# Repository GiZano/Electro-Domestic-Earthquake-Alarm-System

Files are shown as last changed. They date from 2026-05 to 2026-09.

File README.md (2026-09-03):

<div align="center">

# 🌋 QuakeGuard
### Distributed Earthquake Early Warning System

**Full-Stack IoT Architecture for Real-Time Earthquake Detection**




























> 📚 **Technical Specification:** A comprehensive architecture whitepaper is available in the `docs/` directory, compiled via Typst. For a browsable, topic-by-topic reference, check out the [project Wiki](https://github.com/GiZano/QuakeGuard/wiki).

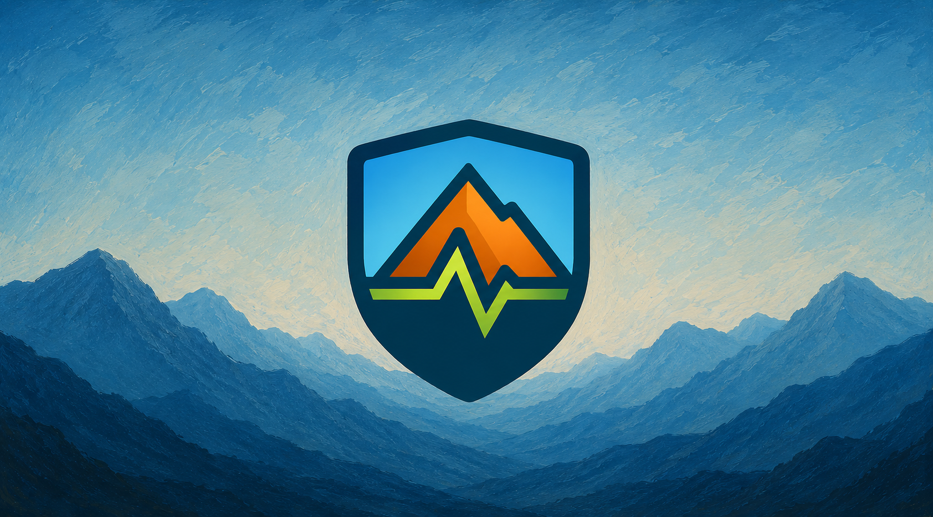
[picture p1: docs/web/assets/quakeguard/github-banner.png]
QuakeGuard Logo


</div>

---

## 📖 Overview

**QuakeGuard** is a full-stack IoT architecture for real-time detection, analysis, and reporting of seismic events. The system transforms everyday household appliances — washing machines, TVs, refrigerators — into a distributed seismic sensor network, each node capable of detecting and reporting earthquake activity autonomously.

Intelligent edge sensors (ESP32-C3 + ADXL345) analyze vibrations locally using professional-grade algorithms and transmit cryptographically signed data to an asynchronous cloud backend. The backend is engineesred to handle the massive traffic spikes — the **Thundering Herd** effect — typical during widespread seismic events, ensuring reliable alarm delivery without bottlenecking. A React Native mobile app receives real-time haptic and visual alerts via WebSocket.

### QuakeGuard Proprietary Hardware

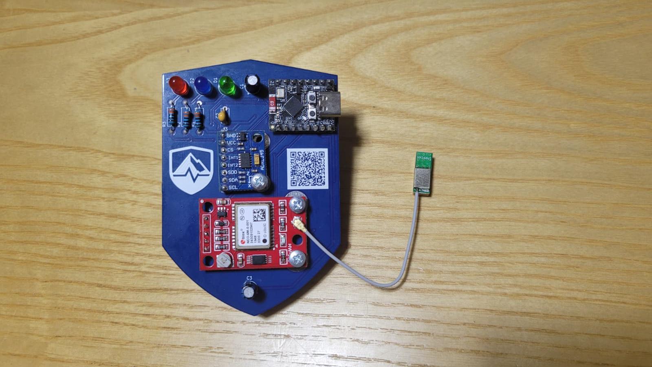
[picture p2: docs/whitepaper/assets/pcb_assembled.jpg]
QuakeGuard v2.0 Assembled PCB


*The QuakeGuard v2.0 fully assembled PCB, featuring the ESP32-C3 SuperMini, the ADXL345 accelerometer, and the u-blox GNSS module. For a complete list of required components, refer to the [Bill of Materials (BOM)](https://github.com/GiZano/QuakeGuard/wiki/Bill-of-Materials) in the Wiki.*

---

## 🏗️ System Architecture

```
ESP32-C3 + ADXL345
       │
       │  MQTT (signed payload)
       ▼
MQTT Bridge ──► POST /readings/ ──► ECDSA Verification
                                              │
                                              ▼
                                        Redis Queue
                                              │
                                              ▼
                                     Background Worker ────►┌───────────┐
                                      │           │ (Queue)  │ AI Worker │
                                      ▼           ▼          │ (Ollama)  │
                               PostgreSQL    Redis Pub/Sub ◄─└─────┬─────┘
                               + PostGIS               │
                                                   ▼
                                            WebSocket Broadcast
                                                  │
                                                  ▼
                                        React Native Mobile App
                                        (Haptic + Visual Alert)
```

The project follows **Microservices** and **Event-Driven Design** principles across three fully independent layers.

---

## 📡 IoT Edge (`firmware/`)

| Feature | Detail |
|---|---|
| Hardware | ESP32-C3 SuperMini + ADXL345 Accelerometer |
| Sampling Rate | 100 Hz |
| Detection Algorithm | STA/LTA (Short Term / Long Term Average) |
| Signal Processing | Digital High-Pass Filter (HPF) to remove gravity |
| Data Structure | Statically allocated Ring Buffers (`RingBuffer<100>` STA, `RingBuffer<1000>` LTA) |
| Security | ECDSA NIST256p cryptographic signing on every payload |
| Transmission | MQTT publish to `quakeguard/telemetry` |
| Provisioning | Automated device handshake on first boot via `POST /devices/register` |
| Secret Injection | Compile-time `ENROLLMENT_TOKEN` via PlatformIO pre-script + `#error` fail-fast |

---

## ☁️ Backend (`backend/`)

| Feature | Detail |
|---|---|
| Framework | FastAPI (Python 3.11), fully async |
| Security | API Key auth, ECDSA signature verification, Anti-Replay (300s window) |
| Message Broker | Redis — decouples ingestion from processing |
| Rate Limiting | Fixed-window 50 req/s per IP via Redis |
| Alert Engine | ML-like magnitude proxy (`M = log10(PGA_calib) + b`), threshold M ≥ 4.5 |
| Deduplication | Redis TTL cooldown lock per zone (60s), prevents alert storms |
| Persistence | PostgreSQL + PostGIS with `recorded_at` timestamps |
| Zone Assignment | Automatic via PostGIS `ST_Contains` spatial query, ordered by `ST_Area` ascending |
| Zone Seeding | 8 pre-populated global macro-regions + "Unknown Region" fallback |
| Observability | `GET /health` — concurrent PostgreSQL + Redis ping |
| Secrets | Fail-fast `RuntimeError` on missing env vars at startup |
| MQTT Bridge | `mqtt_subscriber.py` — forwards MQTT payloads to the secure HTTP pipeline |
| Edge AI | Asynchronous emergency report generation via local Ollama (Llama 3.2) |

---

## 📱 Frontend (`mobile/`)

| Feature | Detail |
|---|---|
| Framework | React Native (Expo) with TypeScript |
| Navigation | Expo Router — 3-tab Bottom Navigator (Monitor, Sensors Map, Settings) |
| State Management | Zustand slices (`usePreferencesStore`, `useAlertStore`) |
| Server State | TanStack Query + Axios — caching, background refetch, retry |
| Real-Time | WebSocket context with exponential backoff reconnection |
| Alert Delivery | SOS haptic vibration pattern + OS push notification via `expo-notifications` |
| Alert History | In-session feed of last 10 critical events |
| AI Report Banner | Inline AI-generated emergency report (summary + recommendations) for the latest alert, with "Report unavailable" badge on failures |
| Offline Mode | Toggle silences WebSocket, halts all TanStack Query polling |
| Notifications | `notificationsEnabled` toggle gates haptics and push notifications |
| Safe Areas | `react-native-safe-area-context` — Dynamic Island and punch-hole compatible |

---

## 🔐 Security Model

Data integrity is paramount in an emergency system. Every telemetry packet is cryptographically secured end-to-end.

```
ESP32 signs payload with ECDSA NIST256p (SHA256)
         ↓
Backend verifies signature against registered public key
         ↓
Timestamp validated within 300-second window (Anti-Replay)
         ↓
API Key checked on every request (X-API-Key header)
         ↓
Payload accepted → Redis Queue
```

**Threat model coverage:**
- ✅ Man-in-the-Middle (MitM) — ECDSA signature verification
- ✅ Spoofing — public key registration + signature check
- ✅ Replay attacks — 300-second timestamp window
- ✅ Brute force — rate limiting 50 req/s per IP
- ✅ Unauthorized access — API Key + enrollment token fail-fast

---

## 🚀 Quick Start

### Prerequisites

- Docker Desktop & Docker Compose
- PlatformIO (VS Code Extension)
- Node.js 18+ & Expo Go (mobile)
- A mobile hotspot or shared WiFi network for ESP32 + backend connectivity

### 1. Configure Environment Variables

```bash
cd backend
cp .env.example .env
```

Edit `.env` and set the required secrets:

```env
# --- Application Secrets ---
IOT_API_KEY=your_secret_key
MOBILE_WS_TOKEN=your_ws_token
ENROLLMENT_TOKEN=your_enrollment_token

# --- Database ---
POSTGRES_DB=quakeguard_db
POSTGRES_USER=developer
POSTGRES_PASSWORD=your_db_password
API_PORT=8000

# --- Cloud MQTT (HiveMQ) ---
MQTT_BROKER=your-cluster-id.s1.eu.hivemq.cloud
MQTT_PORT=8883
MQTT_USERNAME=your_mqtt_username
MQTT_PASSWORD=your_mqtt_password

# --- AI Emergency Reports (hybrid Edge AI architecture) ---
AI_REPORT_ENABLED=true
OLLAMA_HOST=http://127.0.0.1:11434
OLLAMA_MODEL=llama3.2:1b
```

> ⚠️ The backend will refuse to start if any of these are missing — this is intentional fail-fast behavior.

> 💡 **Edge AI Architecture (v2.0.0):** To maximize hardware efficiency and avoid Docker's GPU passthrough overhead, QuakeGuard employs an industrial **Hybrid Edge AI** pattern (similar to NVIDIA Jetson or Tesla FSD architectures). The core AI inference engine (Ollama) runs bare-metal on the host Linux OS, while the application microservices run in Docker and communicate via `network_mode: "host"`.
> 
> **To enable on-premise AI reports:**
> 1. Install Ollama natively on your Linux host: `curl -fsSL https://ollama.com/install.sh | sh`
> 2. Pull the model natively: `ollama pull llama3.2:1b`
> 3. Start the Docker stack with the AI worker profile: `docker compose --profile ai up --build -d`
> 
> Reports are generated entirely on your machine: telemetry never leaves the host.

### 2. Launch the Backend Stack

```bash
cd backend
docker compose up --build -d
```

| Endpoint | URL |
|---|-----|
| API | `http://localhost:8000` |
| Swagger UI | `http://localhost:8000/docs` |
| Health Check | `http://localhost:8000/health` |

### 3. Configure and Flash the IoT Firmware

```bash
cd firmware
cp esp32_config.env.example esp32_config.env
# Edit esp32_config.env with your network IP and ENROLLMENT_TOKEN
```

Flash via PlatformIO. On first boot the device will:
1. Open a WiFi captive portal (`QuakeGuard-Setup`)
2. Connect to your network
3. Automatically register with the backend and receive a `sensor_id`

> 💡 If the sensor registers with `latitude=0.0, longitude=0.0` it will be assigned to "Unknown Region". Hardcode your coordinates in `main.cpp` for correct zone assignment until GPS integration is complete.

### 4. Launch the Mobile App

```bash
cd mobile
npm install
```

Update `constants/config.ts` with your machine's local IP:

```typescript
export const API_BASE_URL = "http://YOUR_LOCAL_IP:8000";
```

Create `.env` in the mobile root:

```env
EXPO_PUBLIC_IOT_API_KEY=your_secret_key
EXPO_PUBLIC_MOBILE_WS_TOKEN=your_ws_token
```

```bash
npx expo start
```

Scan the QR code with Expo Go. Ensure your phone is on the **same WiFi network** as the backend machine.

---

## 🧪 Stress Test

Validates the full pipeline: ingestion → Redis → worker → PostGIS → WebSocket alerts.

```bash
cd backend
export API_URL="http://localhost:8000"
export NUM_SENSORS=150
export CONCURRENCY_LIMIT=50
python -m tests.stress_test
```

**Three phases:**

| Phase | What it tests |
|---|---|
| 🔥 Phase 1 — Firehose | 150 concurrent sensors, rate limiter validation |
| ⚔️ Phase 2 — Security | Bad signature blocked (401), Replay attack blocked (403) |
| 🔍 Phase 3 — E2E | DB persistence verified via polling `GET /sensors/{id}/statistics` |

A successful run ends with `🏆 SYSTEM CERTIFIED`.

---

## 🎮 Demo Mode

Trigger a simulated earthquake instantly from Swagger UI without running the stress test:

```
POST /demo/trigger-earthquake
```

Default payload (works with empty `{}`):
```json
{
  "zone_id": 1,
  "magnitude": 7.5,
  "message": "Simulated Critical Event"
}
```

This publishes directly to the Redis `quake_alerts` channel, bypassing the IoT pipeline entirely and triggering the mobile app alert UI within milliseconds.

---

## 🗺️ Geographic Zones

The database is pre-seeded with 8 global macro-regions. Sensors are automatically assigned to the correct zone via PostGIS spatial query at registration time.

| Zone | Coverage |
|---|---|
| Italy - North | Lombardy, Veneto, Piedmont |
| Italy - Center | Tuscany, Lazio, Umbria |
| Italy - South & Islands | Campania, Sicily, Sardinia |
| Western Europe | France, Spain, Germany, UK |
| North America | USA, Canada, Mexico |
| South America | Brazil, Argentina, Chile |
| East Asia | China, Japan, India |
| Unknown Region | Fallback for unmapped coordinates |

---

## 🔄 CI/CD Pipeline

| Workflow | Trigger | Checks |
|---|---|---|
| `backend-ci.yml` | `backend/**` | Bandit, Safety, stress test |
| `frontend-ci.yml` | `mobile/**` | ESLint, npm audit |
| `iot-ci.yml` | `firmware/**` | PlatformIO compilation |
| `pr-lint.yml` | All PRs | Semantic PR title (`type(scope): message`) |
| `devops-ci.yml` | `.github/workflows/**` | Actionlint workflow validation |

---

## 🗂️ Project Structure

```
QuakeGuard/
├── backend/
│   ├── src/
│   │   ├── main.py              # FastAPI gateway + REST endpoints
│   │   ├── security.py          # ECDSA, API Key, Anti-Replay
│   │   ├── worker.py            # Redis consumer + magnitude + alert engine + AI enqueue
│   │   ├── ai_report_worker.py  # Dedicated AI report consumer (Ollama + state machine)
│   │   ├── ollama_client.py     # Deterministic LLM client (anti-hallucination)
│   │   ├── mqtt_subscriber.py   # MQTT to HTTP bridge
│   │   ├── seed.py              # Geographic zone seeder
│   │   ├── models.py            # SQLAlchemy ORM models (+ EmergencyReport)
│   │   ├── schemas.py           # Pydantic request/response schemas
│   │   └── database.py          # DB engine and session factory
│   ├── tests/
│   │   ├── stress_test.py       # Critical E2E stress test suite
│   │   └── unit/                # Unit tests (worker, ollama client, AI worker, models, ...)
│   ├── init-scripts/
│   │   └── ollama-entrypoint.sh # Auto-pulls the Ollama model on startup
│   ├── build.ps1                # Automatic container publish
│   ├── docker-compose.yml
│   ├── Dockerfile
│   ├── mosquitto.conf
│   ├── requirements.txt         # Python requirements for backend development
│   └── .env.example
├── mobile/
│   ├── app/                         # Expo Router screens
│   │   └── (tabs)/
│   │       ├── index.tsx            # Monitor / Dashboard
│   │       ├── map.tsx              # Sensor Network Map
│   │       └── settings.tsx         # User Preferences
│   ├── api/                         # Axios client + TanStack Query hooks
│   ├── components/                  # Shared UI components
│   ├── store/                       # Zustand state slices
│   ├── context/
│   │   └── WebSocketContext.tsx     # Real-time alert context
│   └── constants/
│       └── config.ts                # Centralized configuration
├── firmware/
│   ├── src/
│   │   ├── main.cpp             # FreeRTOS tasks, STA/LTA, MQTT, provisioning
│   │   ├── DetectionCore.h      # Pure-C++ STA/LTA core (shared firmware/host, R1)
│   │   └── RingBuffer.h         # Statically allocated circular buffer
│   ├── tools/
│   │   └── detect_cli.cpp       # Native host CLI (SIL replay, same core)
│   ├── test/                    # Test scripts to insert into the ESP32
│   ├── key-generator/           # ECDSA key generator for backend testing
│   ├── esp32_config.env.example
│   ├── extra_script.py          # ENV variables injector
│   └── platformio.ini
├── research/                    # SIL validation (ROADMAP R1)
│   ├── fetch_itaca.py           # ITACA download (graceful degradation) / synthetic fallback
│   ├── synthetic.py             # Realistic synthetic dataset generator
│   ├── calibrate_io.py          # Dataset layout I/O + path-injection guard
│   ├── orchestrator.py          # Compile & run the host C++ CLI (subprocess bridge)
│   ├── metrics.py               # Sensitivity, False-Alarm Rate, latency, ROC
│   ├── calibrate.py             # TRIGGER_RATIO x NOISE_FLOOR sweep (F1 maximization)
│   ├── plot_roc.py              # ROC curve figure for the paper
│   ├── requirements.txt         # matplotlib (optional, plotting)
│   └── README.md                # Dataset layout, unit conversion, licensing policy
└── docs/                            # Technical Documentation
    ├── main.typ                     # Typst Whitepaper Entrypoint
    ├── 01-architecture.typ          # System Architecture & Overview
    ├── 02-hardware.typ              # Hardware & Edge Computing (ESP32-C3)
    ├── 03-security.typ              # Cryptographic Security & Provisioning
    ├── 04-broker.typ                # Data Plane & Message Broker (MQTT)
    ├── 05-backend.typ               # Backend Services & Event Processing
    ├── 06-mobile.typ                # Mobile Client & Live Telemetry
    ├── 07-deployment.typ            # Deployment & CI/CD
    └── 08-ai.typ                    # AI Emergency Report Service (v1.2.0)
```

---

## 🔮 Roadmap

| Version | Focus |
|---|---|
| **v1.0** | ✅ Released — edge seismic detection on ESP32, local alerts |
| **v1.1** | ✅ Released — HiveMQ Cloud MQTT (TLS), ngrok HTTPS tunnel, security hardening |
| **v1.2** | ✅ Released — On-Premise AI Worker (Local Ollama / Llama 3.2) for privacy-preserving emergency reports |
| **v1.2.1** | ✅ Released — Geo-Zoning & Cooldown Fragmentation — geohash Redis zone index (FastAPI/PostGIS source of truth), per-area cooldown, GNSS-ready data model (`Sensor.last_fix_at`, `Reading.lat/lon`), per-zone live seismograph |
| **v1.2.2** | ✅ Released — Zero-Trust Serial Fallback — signed telemetry over USB CDC (serial) when MQTT is unreachable |
| **v2.0.0** | ✅ Released — Triangulation (multi-node spatial correlation), Hybrid Network Architecture, Automated DevOps Orchestration (Ptyxis), Local Factory Provisioning, GNSS sync, NTP+PPS, ADXL calibration, and INGV FDSN SIL validation |
| **v2.0.1** | ✅ Released — Documentation & Zenodo Sync: PDF/Wiki architectural coherence (Cloudflare, 300s anti-replay), CERN-OHL hardware licensing, SIL vs Firmware threshold clarification, and `CITATION.cff` bump |
| **v2.1** | Data Dashboards — Grafana dashboards for real-time visualization of seismic telemetry |
| **v2.1.1** | Timeseries DB & Mobile Fix — migration to TimescaleDB/InfluxDB; per-sensor chart isolation in React Native mobile |
| **v2.2** | Heterogeneous Edge Intelligence — hybrid Tier A (STA/LTA) + Tier B (quantized CNN) decision fusion |
| **Future** | Cloud IaC — Kubernetes + Terraform auto-scaling platform (see [ROADMAP.md](ROADMAP.md)) |

### #Research — Scientific Validation (SIL)

| Node | Focus |
|---|---|
| **#Research** | Parallel ongoing node — SIL cross-validation: replay of the exact production C++ STA/LTA core (`DetectionCore.h`) on the host via the same C++ source, Python-only as orchestrator, ROC metrics + AI benchmarking (latency P50/P99, hallucination rate). R1 pipeline (core isolation, host CLI, orchestrator, metrics, calibration) implemented; see [ROADMAP.md](ROADMAP.md) |

---

## 🏆 Awards & Recognition

QuakeGuard's architecture and real-world applicability have been recognized in the following academic and industrial contexts:

* 🥇 **1st Place Overall - Institute Project Day (2025):** Awarded best technical project out of ~20 prototypes across four engineering disciplines (Computer Science, Automation, Mechanics, Chemistry). The full-stack architecture was evaluated and awarded by an industrial jury featuring technical representatives from **Siemens, ABB, SORINT.lab, SAME, Ferrero, and Confindustria**.
* 🎓 **Academic Origin & Consultation:** The system's conceptualization originated during the 2025 CQIIA-MatNet Summer School (Università di Bergamo). The distributed network logic and spatial deployment strategy were subsequently refined following technical consultations with Prof. F. Finazzi.
* 🏅 **GF Marilli Competition:** [Currently competing - Pending evaluation].

---

## 📄 License

This project is licensed under the **GNU Affero General Public License v3.0 (AGPL-3.0)**.
See the [LICENSE](LICENSE) file for details.

---

<div align="center">

**Developed by [GiZano](https://giovanni-zanotti.is-a.dev) and [riccardo0731](https://riccardo0731.github.io)**
<br>
*Open Source — AGPL-3.0 License*
<br><br>

</div>

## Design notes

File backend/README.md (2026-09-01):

# QuakeGuard Backend Service

QuakeGuard is a distributed, high-throughput backend system designed for the real-time ingestion, cryptographic validation, and processing of seismic data from IoT devices.

This repository hosts the **API Gateway**, **Background Worker**, and **Persistence Layer** definitions, serving as the core infrastructure for an Earthquake Early Warning (EEW) system.

---

## 📂 Project Structure

The project is organized as a modular microservice architecture:

```text
backend/
└── api/
    ├── init-scripts/       # SQL initialization scripts (PostGIS)
    │   └── ollama-entrypoint.sh  # Auto-pulls the Ollama model on startup
    ├── src/                # Source Code
    │   ├── main.py         # FastAPI Gateway & REST Endpoints
    │   ├── worker.py       # Stream consumer (Redis Streams, batched persistence)
    │   ├── ingest.py       # Redis Streams ingestion substrate (group/DLQ/recovery)
    │   ├── timescale.py    # Idempotent TimescaleDB hypertable + aggregates migration
    │   ├── geo.py          # Geohash zone-index (Redis) + candidate pruning
    │   ├── ai_report_worker.py  # Dedicated AI report consumer (Ollama + state machine)
    │   ├── ollama_client.py     # Deterministic LLM client (anti-hallucination)
    │   ├── database.py     # SQLAlchemy Connection & Pool config
    │   ├── models.py       # ORM Models (GeoAlchemy2 + EmergencyReport)
    │   └── schemas.py      # Pydantic DTOs
    ├── scripts/
    │   └── load_test.py    # Load generator (N sensors at H Hz, stream or HTTP)
    ├── docker/
    │   └── postgres-timescale.Dockerfile  # TimescaleDB + PostGIS DB image
    ├── tests/              # Testing Suite
    │   ├── __init__.py
    │   ├── stress_test.py  # Load testing & ECDSA simulation tool
    │   └── unit/           # Unit tests (worker, ollama, AI worker, models)
    ├── .venv/              # Local Python Environment
    ├── build.ps1           # Build helper script
    ├── docker-compose.yml  # Container orchestration
    ├── Dockerfile          # Python runtime environment
    └── requirements.txt    # Project dependencies
```

---

## 🏗 System Architecture

The system operates on three decoupled layers:

1.  **Ingestion Layer (FastAPI):**
    * **Role:** Acts as the secure gateway for IoT sensors.
    * **Features:**
        * Asynchronous request handling (`async/await`).
        * **Zero-Trust Security:** Enforces ECDSA (NIST256p) signature verification with SHA-256 hashing on every payload.
        * **Polyglot Crypto Support:** Handles both DER (MbedTLS/C++) and RAW (Python/JS) signature formats.
        * **O(1) enqueue:** Valid payloads are appended to a **Redis Streams** bus (`readings:stream`) instead of touching the database — the API stays fast no matter how many sensors emit.

2.  **Processing Layer (Worker):**
    * **Role:** Drains the stream via consumer groups and persists + analyzes the data.
    * **Features:**
        * **Horizontally scalable:** `docker compose scale worker=N` — Redis balances deliveries across consumers; `XAUTOCLAIM` reclaims entries left pending by crashed workers (at-least-once delivery).
        * **Batched persistence:** a stream batch (default 64 heartbeats) is committed to PostgreSQL in one transaction.
        * **Poison-message isolation:** unparseable/failing heartbeats are parked on the `readings:dlq` stream and ACKed, so they can never stall the group.
        * Triggers persistent `Alerts` when predefined thresholds are breached (Redis `SET NX` cooldown deduplication).

3.  **Persistence Layer:**
    * **TimescaleDB + PostGIS (single image):** `readings` is a TimescaleDB *hypertable* chunked on `recorded_at` (continuous aggregate `readings_minute` serves the dashboard rollups; compression + retention). PostGIS remains the authoritative source for zone geometry.
    * **Redis:** Streams for ingestion buffering, Pub/Sub for real-time alert distribution, geohash zone-index + cooldown keys for the alerting fast path.

---

## 🚀 Installation & Setup

### Prerequisites
* **Docker** & **Docker Compose**
* **Python 3.11+** (Optional, for local testing)

### 1. Environment Configuration
The system relies on environment variables. Ensure your `.env` or Docker configuration includes:

```env
DATABASE_URL=postgresql://developer:development_pass@db:5432/monitoraggio_db
REDIS_URL=redis://redis:6379/0

# --- Optional: AI Emergency Reports ---
# Enables report enqueueing from the alert engine (default: false)
AI_REPORT_ENABLED=true
OLLAMA_HOST=http://ollama:11434
OLLAMA_MODEL=llama3.2:1b
```

### 2. Build and Deployment
Navigate to the `api` directory and launch the stack:

```bash
cd api
docker-compose up -d --build
```

The API will be accessible at: `http://localhost:8000`

### 3. Optional — Enable AI Emergency Reports (Hybrid Edge AI)
To maximize performance and avoid Docker virtualization overhead for GPU drivers, QuakeGuard uses a hybrid Edge AI architecture (following NVIDIA Jetson/Tesla FSD best practices). The AI model runs natively on the host OS, while the `ai-worker` runs in Docker.

1. Install Ollama natively on your Linux host machine:
   `curl -fsSL https://ollama.com/install.sh | sh`
2. Download the model:
   `ollama pull llama3.2:1b`
3. Start the Docker stack with the `ai` profile:
   ```bash
   cd api
   docker-compose --profile ai up -d --build
   ```

The `ai-worker` container will automatically connect to your native Ollama instance using the host network. Reports are generated entirely on the host — telemetry never leaves your machine.

### 4. API Documentation
Interactive Swagger UI is available at:
`http://localhost:8000/docs`

---

## 📡 API Endpoints Overview

### 🛠️ Registration (Admin & Setup)
Endpoints for provisioning the infrastructure.

* **POST** `/zones/` - Create a new monitoring zone.
* **POST** `/sensors/` - Register a new sensor.
    * *Note:* Requires the sensor's ECDSA Public Key (Hex format).
* **GET** `/zones/` - Retrieve available zones.
* **GET** `/sensors/` - Retrieve registered sensors.

### 📍 Geo-Location (v1.2.1)
* **GET** `/zones/locate?latitude=..&longitude=..` - Resolve a GPS fix into the smallest containing monitored zone (powers "Detect my zone").
* **GET** `/zones/{zone_id}/readings` - Fetch the most recent readings emitted by sensors of a single zone (per-zone seismograph feed).
* **DELETE** `/zones/{zone_id}/readings` - Clear the telemetry emitted by a single zone (returns `{ "deleted": n }`).

### 📥 Data Ingestion (IoT)
* **POST** `/readings/` - High-frequency ingestion endpoint.
    * **Payload:** Telemetry data including `value`, `device_timestamp`, and `signature_hex`.
    * **Security:** Rejects any payload with an invalid or missing digital signature.

### 📊 Data Retrieval & Analytics
* **GET** `/zones/{zone_id}/alerts` - Retrieve confirmed seismic alerts for a specific area.
* **GET** `/sensors/{sensor_id}/statistics` - Get aggregated metrics (Count, Avg, Max, Min) for sensor diagnostics.

### 🤖 AI Emergency Reports (v1.2.0)
* **GET** `/reports/{alert_id}` - Retrieve the AI-generated emergency report for a confirmed alert (persisted; useful after a WebSocket reconnect).

### 🟢 System
* **GET** `/health` - Detailed status check of API, Database, and Redis connectivity.

---

## ⚙️ Technical Specifications

### Cryptography & Security
The backend enforces strict cryptographic standards to prevent spoofing or replay attacks:
* **Algorithm:** ECDSA (Elliptic Curve Digital Signature Algorithm).
* **Curve:** NIST P-256 (secp256r1).
* **Hash Function:** SHA-256.
* **Format:** Accepts **DER encoded** signatures (standard for ESP32/MbedTLS) with a fallback to RAW formats.

### High-Concurrency Configuration
To handle bursts of traffic during seismic events, the database engine is optimized:
* **Pool Size:** 40 persistent connections.
* **Max Overflow:** 60 additional temporary connections (Total capacity: 100 concurrent threads).
* **Pre-Ping:** Enabled to prevent stale connection errors.

### Scaling (right-sized)
| Tier | Configuration | Sustained write rate |
| :--- | :--- | :--- |
| 150 sensors (test) | 1 worker, default settings | ~30 msg/s (1 reading / 5 s) |
| 10k sensors | `scale worker=N`, TimescaleDB hypertable | ~2k msg/s (1 Hz each) on 1 Postgres node |
| 1M sensors | + EMQX federation, Kafka/Redpanda buffer, ClickHouse analytics | beyond single-node; ports are designed, not deployed |

The TimescaleDB migration (`src/timescale.py`) is idempotent and **fails closed**: on a stock PostGIS container every step is skipped with a warning and the service keeps running on the plain relational table. Provisioning happens automatically at startup and via `python -m src.timescale`.

Load generator for capacity planning:

```bash
# 150 sensors @ 1 Hz into the stream bus (matches the CI requirement)
python scripts/load_test.py --sensors 150 --hz 1 --duration 60
# End-to-end through the FastAPI ingress
python scripts/load_test.py --sensors 150 --hz 1 --mode http --api http://localhost:8000
```

---

## 🧪 Stress Testing

A specialized end-to-end stress suite lives in `tests/stress_test.py`. It simulates a fleet of **150 sensors** (configurable via `NUM_SENSORS`) firehosing cryptographically valid MQTT telemetry, verifies end-to-end persistence, and runs active security attacks (invalid signature + replay) against the API.

**To run the test:**

1.  Ensure the Docker stack is running.
2.  Install test dependencies:
    ```bash
    pip install aiohttp ecdsa aiomqtt
    ```
3.  Execute the script:
    ```bash
    python -m tests.stress_test
    ```

**Success Criteria:**
The test should report a 100% success rate (HTTP 202 Accepted) with no signature validation errors.

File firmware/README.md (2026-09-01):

# QuakeGuard - Distributed Earthquake Early Warning System
### Firmware Version: v2.0.0

## 1. Project Overview
QuakeGuard is an IoT-based seismic detection node designed for the **ESP32-C3 SuperMini** platform. It utilizes an **ADXL345** accelerometer to detect ground vibrations in real-time using the **STA/LTA (Short Term Average / Long Term Average)** algorithm.

Upon detecting a seismic event, the device constructs a JSON payload containing the magnitude and timestamp, cryptographically signs it using **ECDSA (NIST256p)**, and transmits it via HTTP POST to a central server.

## 2. Hardware Architecture

### Target Platform
* **Microcontroller:** ESP32-C3 SuperMini (RISC-V)
* **Sensor:** ADXL345 Digital Accelerometer (I2C Interface)

### Pin Configuration (Critical)
Due to the specific layout of the ESP32-C3 SuperMini, the I2C bus is forced via software to the following GPIOs:

| Component Pin | ESP32-C3 GPIO | Notes |
| :--- | :--- | :--- |
| **SDA** | **GPIO 7** | Requires internal Pull-Up (Handled by Firmware) |
| **SCL** | **GPIO 8** | Requires internal Pull-Up (Handled by Firmware) |
| **VCC** | **3.3V** | **Do not use 5V** (Risk of sensor damage) |
| **GND** | **GND** | Common Ground |

## 3. Key Features

### Signal Processing (DSP)
* **Dynamic Allocation:** Sensor objects are instantiated dynamically after boot to prevent I2C bus race conditions.
* **Digital High-Pass Filter (HPF):** Removes the DC component (gravity) to isolate vibration data.
* **Noise Gate:** Ignores micro-vibrations below **0.04G** to prevent false positives from electrical noise.
* **Dropout Protection:** Automatically discards invalid frames (0G readings) caused by temporary wiring disconnects.

### Security Subsystem
* **Identity:** Unique Device Identity based on a persistent **ECDSA Private Key** stored in NVS (Non-Volatile Storage).
* **Integrity:** Every payload is hashed (SHA-256) and signed. The server can verify the origin using the device's Public Key.
* **Replay Protection:** Timestamps are synchronized via NTP (`pool.ntp.org`) to prevent replay attacks.

### USB Serial Fallback 
When the MQTT data plane is unreachable, the node re-certifies each event and emits it over the **USB CDC** port as a machine-readable frame so a co-located host still receives data during offline simulations:

```
[QG:FB]{"value":250,"sensor_id":42,"device_timestamp":1720000000,"signature_hex":"..."}
```

* **Identical signing** to the MQTT data plane — the backend ECDSA + replay-window checks apply unchanged.
* **USB-host aware:** frames are only written while a real USB host is attached (`Serial.isConnected()`, HWCDC). Plugged into a power-only charger, events are **retained in an in-memory ring** (last 100) instead of being sent to a dead port, and are drained FIFO when a path returns.
* **Offline wall clock:** timestamps come from a software clock anchored at the first NTP sync, so they stay valid after WiFi drops; retained events are re-signed with the current time at drain.
* **Host bridge:** `tools/serial_bridge.py` reads the CDC device and forwards each frame to the ingestion pipeline:
  ```bash
  pip install pyserial requests
  python tools/serial_bridge.py --port /dev/ttyACM0 --api-key "$IOT_API_KEY"
  ```
* **Toggle:** set `SERIAL_FALLBACK_ENABLED=0` in `esp32_config.env` for MQTT-only behaviour.

## 4. Configuration

Before compiling, ensure the network and server credentials in `src/main.cpp` are updated:

```cpp
#ifndef WIFI_SSID
  #define WIFI_SSID "YOUR_WIFI_NAME"
#endif

#ifndef SERVER_HOST
  #define SERVER_HOST "192.168.1.X" // Your Backend IP
#endif
```

### HTTPS Tunnel Compatibility (IoT TLS clients)
The device registers over plain HTTPS using the ESP-IDF **mbedTLS** stack. The ngrok **free-tier** edge terminates TLS handshakes from such clients via **JA3 fingerprinting** (bot-protection) *before* any HTTP header — including `ngrok-skip-browser-warning` — can be read, so the request never reaches the backend (`HTTP Code: -1`, `SSL - The connection indicated an EOF`). For the dev tunnel we use a **Cloudflare quick tunnel** (`cloudflared tunnel --url http://localhost:8000`), whose edge does not fingerprint IoT TLS clients, or a real HTTPS domain in production. Set `SERVER_HOST` (no scheme) and `SERVER_PROTOCOL` accordingly.

> **Dev tunnel lifecycle (ephemeral).** The quick tunnel is account-less and has no uptime guarantee: it dies with the `cloudflared` process and the URL changes at **every restart**. The node only calls the HTTP endpoint at **first boot** (provisioning); after that it publishes over MQTT. If you erase the node's NVS (re-provisioning) or build fresh, restart the tunnel and update `SERVER_HOST` (firmware) and `EXPO_PUBLIC_API_BASE_URL` (mobile) with the new URL:
> ```bash
> ~/bin/cloudflared tunnel --url http://localhost:8000 --no-autoupdate --protocol http2
> ```
> `--protocol http2` is required on networks that block the default QUIC edge connection. For a stable URL, use a named Cloudflare tunnel with your own domain.

### Enabling the Optional GNSS Module (Experimental)
The firmware ships with a **GNSS heartbeats module**, disabled by default. When enabled, the device reads a connected UART GNSS receiver, computes a geohash from the current fix, and includes it in every heartbeat sent to the server (used by the geo-spatial zone-alerting feature on the backend).

* **Makefile/environment flag:** set `GNSS_ENABLED=1` in the `esp32_config.env` file (see `esp32_config.env.example`) and rebuild. Without the flag (or without the file), the module compiles out entirely — zero RAM/flash overhead.
* **Hardware wiring (UART):** connect the GNSS receiver TX to a free UART-capable pin and set `GNSS_UART_TX_PIN` / `GNSS_UART_RX_PIN` in `src/gnss/GnssModule.h`.
* **Behavior while unlocked:** the module stays **UART-silent** (no `$GxRMC`/`$GxGGA` requests) so legacy GeoGuessr-style debugging on the same UART line is preserved.
* **Fallback:** if the receiver never produces a fix, the heartbeat is sent without location and the server falls back to the device's registered location.

## 5. Installation & Provisioning

### Step 1: Upload Firmware
Connect the ESP32-C3 via USB and upload the firmware using PlatformIO or Arduino IDE.

### Step 2: Automatic Registration (no manual step)
On the **first boot** the device performs the automated handshake:

1. Generates a fresh **ECDSA key pair** and seals the private key in NVS.
2. Opens the WiFi captive portal (`QuakeGuard-Setup`) so you can connect it to your network.
3. POSTs `/devices/register` with its `public_key_hex`, `mac_address`, `enrollment_token` and (GNSS-ready) coordinates.
4. Receives its `sensor_id` back from the backend and persists it in NVS.

No per-device configuration is needed for distribution — the backend assigns the ID
and the zone (via PostGIS) at registration time. The serial output shows:

```text
[PROV] SUCCESS! Assigned Sensor ID: 7
[PROV] Public key: 3059301306072a8648ce3d0201...
```

## 6. LED / Serial Status Codes

* `[SYS] Sensor OK`: Hardware initialization successful.
* `[SENSOR] Stabilizing...`: Calibrating the accelerometer baseline (do not move the device).
* `[SENSOR] EARTHQUAKE DETECTED!`: The STA/LTA ratio exceeded **1.8** and intensity exceeded **0.04G**.
* `[NET] Transmission Successful`: JSON payload accepted by the server.
* `[NET] MQTT Publish OK.` / `[NET] Serial Fallback Publish OK.`: event dispatched over the active path.
* `[NET] No delivery path: event retained in ring.`: MQTT down and no USB host — the event is buffered for later drain.

## 7. Troubleshooting

### "Sensor Hardware Failure" / "Fatal Error"
If the serial monitor displays `[FATAL] Sensor Check Failed`:
1.  **Cold Boot:** Unplug the USB cable completely for 5 seconds (the ADXL345 must lose power to reset). Reconnect and retry.
2.  **Check Wiring:** Ensure SDA is on Pin 7 and SCL is on Pin 8.
3.  **Voltage:** Verify the sensor is receiving 3.3V.

### "403 Forbidden" from Server
The device is connected to WiFi but the server rejected the signature.
* **Solution:** Re-connect to Serial Monitor, reset the board, copy the **Public Key**, and update the server's authorized devices list.

## 8. License
Copyright (c) 2026 GiZano. All rights reserved.
intended for educational and research purposes.

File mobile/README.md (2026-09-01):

# QuakeGuard - Mobile Application

**QuakeGuard Mobile** is a React Native application built with Expo (SDK 50+), designed to provide real-time monitoring of seismic activity. It interfaces with a custom Python backend and IoT sensor network to visualize system status and sensor locations.

## 🛠 Technology Stack

- **Framework:** React Native (Expo Router)
- **Language:** TypeScript
- **State Management:** Zustand
- **Maps:** React Native Maps
- **UI/Icons:** Lucide React Native
- **Animations:** React Native Reanimated

## 🚀 Features

### 1. 🛡️ Monitor Dashboard (Home)

- **Live Data:** Real-time readings via WebSocket push + REST polling (`GET /readings/`).
- **Visual Status:** Displays a "System Secure" (Green) or "Seismic Alert" (Red) status based on recent data.
- **Haptic Feedback:** Triggers device vibration when the system state transitions from Secure to Alert.
- **Animations:** Uses `react-native-reanimated` for a pulsing shield effect during active alerts.
- **AI Emergency Reports:** When an alert is confirmed, the backend generates a report via a local Ollama LLM and pushes it over the `ai_reports` WebSocket channel. The app displays an inline banner for the latest report and a card in the alert history feed (summary + recommendations), with an "AI Report Unavailable" badge if generation failed. Reports can be re-fetched via `GET /reports/{alert_id}` after a reconnect.

### 2. 🗺️ Sensor Map (WIP)

- **Data Visualization:** Fetches sensor coordinates (`GET /sensors/`) and displays them on a map interface.
- **Status Indicators:** Markers change color based on the active/inactive status of the sensor.

## ⚠️ Known Issues

- **Map Marker Crash:** navigating to the Map tab currently triggers the error: `Error while updating property 'coordinate' of a view managed by AIRMapMarker`.
  - _Status:_ Under Investigation.
  - _Suspected Cause:_ Data type mismatch (string vs number) in the coordinate payload from the backend.

## ⚙️ Installation & Setup

### 1. Prerequisites

Ensure you have the following installed:

- Node.js (LTS version recommended)
- Expo CLI
- The QuakeGuard Backend running locally.

### 2. Install Dependencies

Navigate to the project root and install the required packages:

```bash
npm install
# or
npx expo install
```

### 3. Configuration (Critical Step)

Before running the application, you must configure the API endpoint to match your local network environment. The application cannot access `localhost` if running on a physical device or Android Emulator.

Open `constants/config.ts` and update the IP address:

```typescript
// constants/config.ts
export const API_BASE_URL = "http://YOUR_LOCAL_IP:8000";
// Example: 'http://192.168.1.50:8000'
```

### 4. Running the Application

Start the development server:

```bash
npx expo start -c
```

- Press **"a"** to run on Android Emulator.
- Press **"i"** to run on iOS Simulator (macOS only).
- Scan the QR code with the **Expo Go** app to run on a physical device (ensure the device is on the same Wi-Fi network).

## 🐛 Troubleshooting

**Network Errors / Backend Unreachable:**
If the app fails to connect to the backend:

1.  Ensure the backend is running and accessible.
2.  Verify that your firewall allows connections on port 8000.
3.  **WSL Users:** If running the backend on WSL2, the network bridge might fail. Try running Expo with the tunnel option:

```bash
npx expo start --tunnel
```

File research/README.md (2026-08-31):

# QuakeGuard — SIL Research (ROADMAP R1)

Software-in-the-Loop cross-validation of the STA/LTA detection core against the
INGV/ITACA strong-motion dataset. The detection runs on **the exact same C++
code** as the ESP32 firmware (`firmware/src/DetectionCore.h`), guaranteeing
numerical equivalence for the IEEE paper.

```
┌─ synthetic.py ─── generate a realistic synthetic dataset (no network) for CI / smoke tests
│                        (canonical fallback provider; same layout as the future ESM path)
│
├─ calibrate_io.py ── load events/ + ground_truth.json
│
├─ orchestrator.py ── compile & run the host C++ CLI (firmware/tools/detect_cli.cpp)
│                         sole Python↔C++ bridge (subprocess)
│
├─ metrics.py ────── Sensitivity/Recall, False-Alarm Rate, latency, ROC
│
├─ calibrate.py ──── sweep TRIGGER_RATIO x NOISE_FLOOR, maximize F1
│
└─ plot_roc.py ───── ROC curve figure for the paper
```

## Graceful degradation (I/O contract)

`synthetic.py` emits a **fixed** dataset layout. Downstream modules
(`metrics.py`, `calibrate.py`, the C++ core) never know whether they process a
real earthquake or a locally generated mock — that is the point. Resolution:

- **Real path (INGV FDSN).** The INGV downloader queries the
  **public FDSN web-service** using **ObsPy** (`obspy.clients.fdsn`), downloads
  the open waveforms from the **IV** and **MN** networks (for the same historical events),
  and converts them into the shared layout. No registration token is required, so the real path can work
  headlessly in CI/CD. This replaces the previous ITACA/ESM parsers, as the IT network waveforms are restricted.
- **Synthetic fallback (default).** When no network/ESM is available,
  `synthetic.py` generates *realistic* accelerometer-like mocks: white background
  noise, a high-frequency P impulse, a larger/lower-frequency S arrival, and a
  1 G gravity offset (matching the firmware's `sensors_event_t`). The exact
  P-arrival is written to `ground_truth.json` as the reference.

```
┌────────────────────────────────────────────────────────────────────────┐
│  synthetic.py                                                           │
│    (fallback) ───────▶ realistic synthetic generator ──── P known       │
│                                                                         │
│  download_esm.py (ObsPy public INGV FDSN) ───▶ t,ax,ay,az  (m/s²)      │
└──────────────────────────────▶ (identical layout below) ────────────────┘
```

## Dataset layout

The dataset is **not** committed to git (see `research/README.md` re: license
and weight). Generate it with:

```bash
# realistic local / CI mock (no network required)
python research/synthetic.py research/data_synth
# real INGV FDSN (public API, open networks IV/MN, no token)
python research/download_esm.py research/data
```

Layout produced by every path (units **m/s^2**, the same as the firmware
`Adafruit sensors_event_t`; gravity baseline ~9.8 on Z):

```
<dataset>/
    events/<event_id>.csv      # t,ax,ay,az  (100 Hz, m/s^2; '#' = comment)
    ground_truth.json          # [{"event_id": ..., "p_arrival_s": ...}]
```

## Run the full pipeline

```bash
# 1. build the host CLI (or let orchestrator.py compile it)
g++ -std=c++11 -I firmware/src firmware/tools/detect_cli.cpp -lm -o firmware/tools/detect_cli

# 2. calibrate against the dataset
python research/calibrate.py research/data --out research/out/calibration.json

# 3. print the ROC figure
python research/plot_roc.py research/out/calibration.json --roc-out research/out/roc.png
```

## Unit conversion (Gal → m/s²)

ESM/ITACA flatfiles carry accelerations in **Gal** (cm/s²). The parser converts
to the same m/s² scale the firmware/C++ core expects:

```
Acceleration (m/s²) = Acceleration (Gal) / 100
1 G = 980.665 Gal = 9.8 m/s²
```

## Licensing & the real Zenodo dataset

- **INGV (IV/MN Networks) = Open Data.** The INGV FDSN web service distributes continuous waveforms for the IV and MN networks as open data.
  The **derived calibration dataset** (parsed events + ground truth in the shared
  layout) is therefore **re-distributable**: it can be published as an open
  validation artifact on Zenodo with its own DOI. Cite INGV in `CITATION.cff`.
- **ITACA / ESM = Restricted.** The IT network forbids free redistribution of continuous raw waveforms without logging into their portal. By using the IV/MN networks, we bypassed this block.
- **License re-verification gate.** Before publishing ANY derived artifact,
  re-check the current INGV license terms (they can change) and update
  `CITATION.cff` accordingly at release time.
- **QuakeGuard MEMS Dataset (yours).** The Zenodo dataset with its own DOI is
  the accelerogram recorded by your physical ESP32-C3 nodes (Tier A) — your own
  IP, licensed freely (e.g. MIT / CC-BY 4.0). ITACA/ESM serve only as reference
  ground truth for validating the detection algorithm (R1), never as a
  publishable output. See `CITATION.cff` for the ESM/ITACA citations once published.

## DOI workflow (QuakeGuard MEMS Dataset)

1. Collect the real MEMS accelerograms from your nodes into the documented
   layout.
2. Zip: `cd research && zip -r quakeguard_mems_v1.3.0.zip data/`
3. Upload to **Zenodo** → metadata (title, authors + ORCID, license, keywords)
   → **Publish**.
4. Append the returned DOI (type `doi`) to `CITATION.cff`.
5. Do **not** commit the raw data (gitignored); the README documents re-download.

> The DOI is assigned **once**; fix data only by publishing a new Zenodo version.

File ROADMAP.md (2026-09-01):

# ROADMAP — QuakeGuard

> Semantic Versioning progression.

---

## v1.0.0 — Edge Seismic Detection (Released)

Edge seismic detection on ESP32 with local alerts.

- ADXL345 acquisition at 100 Hz with STA/LTA triggering
- ECDSA signature on every payload
- Local alert via LED / serial

---

## v1.1.0 — Cloud & Security (Released)

Data Plane migration to MQTT Cloud (HiveMQ), REST Control Plane (HTTPS) and TLS security.

- Data Plane: ESP32 → HiveMQ Cloud (port 8883, TLS + username/password)
- Control Plane: HTTPS tunnel for REST provisioning — *Cloudflare quick tunnel* in dev (the ngrok free-tier edge is unusable by ESP32 IoT clients: it terminates ESP-IDF/mbedTLS TLS handshakes via JA3 fingerprinting)
- `setInsecure()` for TLS handshake on ESP32
- MQTT Bridge (Python Paho) with TLS
- Working mobile dashboard with live data
- Active CI/CD

---

## v1.2.0 — On-Premise AI Reports (Released)

On-premise AI integration (LLM in the backend) to generate textual emergency reports from MQTT data.

- ✅ On-premise LLM via Ollama (`llama3.2:1b`) consuming confirmed alerts — telemetry never exposed
- ✅ Automatic emergency report generation: magnitude, zone, timestamp, recommendations (deterministic, anti-hallucination)
- ✅ WebSocket push of the AI report to the mobile app (banner + history card)
- ✅ `PENDING → COMPLETED | FAILED` state machine with DLQ and explicit fallback
- ✅ REST endpoint `GET /reports/{alert_id}`

---

## v1.2.1 — Geo-Zoning & Cooldown Fragmentation (GNSS-ready) (Released)

Geographic zone division designed so the system is ready for the GNSS upgrade (v1.3). The alert cooldown is fragmented from the coarse macro-region level down to a per-area geohash granularity, and the zone-assignment hot path is offloaded from PostGIS queries to a Redis geohash index — with PostGIS kept as the single source of truth.

> **Blocking prerequisite for v1.3 (GNSS):** real GNSS coordinates replace the hardcoded Rome fix in the firmware (`main.cpp`), so the geo layer must already resolve zones and fragment cooldowns from raw coordinates — not from a fixed registration-time zone.

- ✅ **Geohash zone index (Redis fast path)** — `backend/src/geo.py`: at seed time every zone polygon is decomposed into the set of geohash cells (prec 3, ~156 km) it intersects; `resolve_zone()` (in `main.py`) resolves a coordinate from the Redis SET without a DB round-trip. Redis miss or ambiguous multi-zone match falls back to the authoritative PostGIS `ST_Contains` + `ST_Area ASC` query, so the cache can never assign a wrong zone
- ✅ **Pure-Python geohash encoder** matching PostGIS `ST_GeoHash` — zero new dependencies, deterministic keys shared by seed-time index and runtime lookup
- ✅ **Fragmented cooldown lock** — `alert_cooldown:<geohash>` (prec 4, ~50 km) instead of `alert_cooldown:<zone_id>`: two independent events inside the same overlapping macro-polygon no longer silence each other. Legacy `alert_cooldown:zone:<id>` retained for coordinates-less sensors
- ✅ **GNSS-ready data model** — `Sensor.last_fix_at`, `Reading.latitude`/`longitude`; the ingestion payload carries the sensor's fix + geohash; `/devices/register` re-resolves the zone if a relocated node reports a changed fix
- ✅ **Real spatial tests** — integration tests assert resolution against the seeded PostGIS polygons (Milan, Madrid, Tokyo, unknown point), and `point_to_geohash` is cross-validated against PostGIS `ST_GeoHash`

> **Future hardening (for administrative polygons):** `ST_SimplifyPreserveTopology` + GiST tuning, sizing zones so an event cannot physically reach the adjacent zone (~50–100 km for destructive surface-wave propagation).

---

## v1.2.2 — Zero-Trust Serial Fallback (Released)

Signed telemetry over a serial link (USB CDC) when MQTT/WiFi connectivity is lost, so the host still receives data during offline simulations.

- ✅ **Second consumer of the existing event queue** — `networkTask` dispatches each event to the first available path: MQTT publish (unchanged data plane), USB serial fallback, or in-memory retention ring when no path exists
- ✅ **ECDSA-signed payloads, identical signing to the MQTT data plane** — `SerialFallback.h` builds `[QG:FB]{...}` frames with the exact MQTT JSON; retained events are re-signed with the current wall time at drain so the backend ±300 s replay window accepts them
- ✅ **USB-host-aware retention** — `Serial.isConnected()` (HWCDC) distinguishes a real host from a power-only USB charger: with no host, events are retained in the ring instead of being written to a dead port; drained FIFO when a path becomes available
- ✅ **Offline wall clock** — software clock anchored at the first NTP sync (`epoch_at_sync` + `millis()`), so timestamps stay valid even after WiFi drops; no frames emitted before time is valid
- ✅ **Host-side bridge collecting serial output and forwarding to the ingestion pipeline** — `firmware/tools/serial_bridge.py` reads `/dev/ttyACM0`, filters `[QG:FB]` frames, and POSTs them to `/readings/` with `X-API-Key` (same forwarding as the MQTT bridge)
- ✅ **Automatic first-boot provisioning** — compile-time `SENSOR_ID` shortcut removed; the node POSTs `/devices/register` (public key + MAC + enrollment token + GNSS-ready coords) and the backend assigns the `sensor_id` and zone. Verified live on hardware. Backend accepts NULL geometry when a node has no GNSS fix yet

---

## v1.3.0 — Synchronized GNSS (Released)

Advanced GNSS synchronization of nodes for exact timestamps.

- ✅ Optional GPS/GNSS module on ESP32
- ✅ Correct NTP + PPS timestamps for all nodes
- ✅ Replace hardcoded GPS (Rome coordinates) with real coordinates
- ✅ ADXL345 offset calibration on boot

---

## v2.0.0 — Epicenter Triangulation

Triangulation algorithm. Multi-node spatial correlation combined with AI reports to compute the internal epicenter.

- ✅ Triangulation algorithm from ≥3 nodes
- ✅ Multi-node spatial and temporal correlation
- ✅ Internal epicenter computation
- ✅ AI + triangulation data fusion for precise alerts
- ✅ KiCad schematics and Gerber files of the node PCB (hardware blueprints for the triangulation node) — fabricated and assembled, ready for deployment

---

## v2.0.1 — Documentation & Zenodo Sync (Released)

Documentation-only patch aligning the technical whitepaper, GitHub Wiki, and project website.

- ✅ Typst PDF compilation polished (LLM citation removal, version updates)
- ✅ Architectural Coherence: tunnel architecture (Cloudflare) and threshold/anti-replay values (300s) synchronized across all assets
- ✅ Hardware Documentation: clarified `1.8f` firmware threshold vs `2.4` SIL offline threshold; ROC curve contextualized
- ✅ Project Licensing Health: testing pipelines, AGPL-3.0 software licensing, and CERN-OHL hardware licensing explicitly documented
- ✅ `CITATION.cff` bumped for Zenodo archival

---

## v2.1.0 — Data Dashboards

Grafana dashboards for real-time visualization of seismic telemetry.

- Grafana dashboards for live seismic telemetry
- Real-time visualization of multi-node network activity

---

> **Geo-zoning & cooldown-lock design (relevant for the paper's System-Engineering claim):**
> - **Implemented in v1.2.1:** fragmentation to Geohash keys (`alert_cooldown:<geohash>`),
>   which offloads zone assignment from PostGIS `ST_Contains` to fast Redis lookups
>   and stops overlapping macro-regions from silencing independent earthquakes.
> - **Future:** H3 hex-grid reindexing is re-evaluated when the v2.1 triangulation
>   clustering is designed; daily H3 resolution can replace the coarsen geohash grid
>   with no zone-model change. For real administrative polygons: apply
>   `ST_SimplifyPreserveTopology` + a GiST index; size zones so an event cannot
>   physically reach the adjacent zone (~50–100 km for destructive surface-wave propagation).

---

## v2.2.0 — Heterogeneous Edge Intelligence

Crowning of the engineering phase. Two-tier edge cluster where TinyML is **not** a simple STA/LTA replacement, but a hierarchical Decision Fusion between cheap ubiquitous sensors and intelligent confirmation gates.

> **Blocking prerequisite:** the STA/LTA parameter calibration from **R1** must be completed before drafting/training the v2.2.0 models. Calibration is urgent and runs in parallel with v1.3.

**Tier A — Ubiquitous sensors (ESP32-C3):**
- Low-cost, installable anywhere; STA/LTA + ECDSA signing, unchanged from v1.x
- Produce the **proprietary MEMS dataset** (fills the domain gap vs INGV professional seismometers)

**Tier B — Intelligent confirmation gates (ESP32-S3):**
- Hybrid quantized CNN (INT8) via ESP-DL / TensorFlow Lite Micro
- Activated **only on STA/LTA triggers** to compute the local event probability
- Emits a confidence score that confirms or discards Tier A triggers (Decision Fusion)

---

## v2.3.0 — Right-Sized Ingestion at Scale (Redis Streams + TimescaleDB)

Backend ingestion redesigned so the control plane sustains tens of thousands of sensors on a small footprint instead of degrading into a single-queue toy.

- ✅ **Redis Streams replaces the single-consumer list queue** — producers XADD to `readings:stream` (O(1) append); N worker processes drain via consumer groups (`docker compose scale worker=N`); `XAUTOCLAIM` recovers pending entries across worker restarts (at-least-once delivery); poisoned heartbeats park on the `readings:dlq` stream so they never stall the group — `backend/src/ingest.py`
- ✅ **Batched DB commits** — a stream batch (default 64) is written in one transaction instead of one commit per heartbeat
- ✅ **TimescaleDB hypertable on `readings`** — chunked on `recorded_at`; continuous aggregate `readings_minute` serves the dashboard rollups; compression + retention policies. Migration (`backend/src/timescale.py`) is idempotent and **fails closed** on plain PostGIS (dev/CI)
- ✅ **Statistics fast-path** — `/sensors/{id}/statistics` reads the continuous aggregate when present, falls back to a COUNT otherwise
- ✅ **Single TimescaleDB+PostGIS image** — `backend/docker/postgres-timescale.Dockerfile`, wired into `docker-compose.yml`
- ✅ **Real migration coverage** — dedicated CI job runs the hypertable + aggregate tests against the actual deployment image
- ✅ **Load generator** `backend/scripts/load_test.py` — N sensors at H Hz (default matches the 150-sensor CI requirement), stream or HTTP transport

> **Scale math (design target):** 150 sensors @ 1/5s ≈ 30 msg/s (trivial today); 10k sensors @ 1 Hz ≈ 2k msg/s (bounded by worker count + hypertable inserts, still 1 Postgres node). The MQTT transport already exists (firmware → broker → bridge → API); the bridge stays HTTP-proxying by design — direct MQTT→stream is the documented next step only if the broker becomes the bottleneck.

---

## #Research — Scientific Validation (SIL)

Parallel node (non-semantic). **R1 is the Foundation**: it starts immediately, in parallel with v1.3 (GNSS), and its calibration is urgent because it is the blocking prerequisite for v2.2.0 and the paper.

Software-in-the-Loop (SIL) cross-validation: no logic duplication. It uses **100% of the production C++ code** on both the firmware and the host, guaranteeing numerical equivalence for the IEEE paper.

### R1 — STA/LTA detection cross-validation via SIL (Foundation) (Completed)

> Status: **completed.** The STA/LTA core is isolated in pure C++, compiled natively in CI, and driven by the Python orchestrator with zero logic duplication.
>
> Scheduling: **completed in parallel with v1.3 (GNSS)**. The calibration of the trigger parameters is completed and unblocks v2.2.0 model drafting/training.

- [x] Isolation of the STA/LTA algorithmic core in pure C++, fully decoupled from the ESP32 hardware (no I2C/WiFi/FreeRTOS calls in the algorithmic core) — `firmware/src/DetectionCore.h`
- [x] Native host compilation of the C++ core (same source as the firmware) — `detect_cli.cpp` + CI build
- [x] Python as the **sole orchestrator**: reading the public INGV dataset (accelerograms), passing data to the C++ binary via `subprocess`, collecting trigger points and tracing ROC curves — `research/`
- [x] Metrics: Sensitivity/Recall, False-Alarm Rate, response latency — `research/metrics.py`
- [x] Calibration of the trigger parameters (`TRIGGER_RATIO`, `NOISE_FLOOR`, `HPF_ALPHA`) against ground-truth — `research/calibrate.py`; **real ground-truth download via INGV FDSN** (public API + ObsPy, CC-BY-4.0 flatfiles) — see `research/README.md`

> **Completed full R1 closure:** real ESM/INGV ground-truth validation via ObsPy and ROC curve generated.

### R2 — AI Benchmarking (this is the paper's primary novelty contribution)

- P50/P99 latency benchmark of the local async AI worker (Ollama)
- Measurement of the hallucination rate of the generated reports
- Quantification of the privacy/latency advantage vs Cloud baseline

> **Two distinct claims — do not conflate them in the paper:**
> - **Self-hosted, data-sovereign LLM.** Inference runs inside the Docker network
>   (`http://ollama:11434`), uses no third-party inference API, and telemetry never
>   leaves the deployment. *True regardless of deployment target (defensible).*
> - **Local-first resilience** is a *deployment property*, not a software property:
>   it holds only when the full alert path (local MQTT broker → bridge → AI worker)
>   runs on an on-premise host co-located with the community. **Today the alert path
>   uses HiveMQ Cloud, so the alert path still depends on the WAN.** Claim this only
>   for the on-premise topology.
>
> **Determinism is a hypothesis, not a guarantee:** `temperature=0`, `top_k=1`
> (greedy decoding) remove *stochastic variance*, but the model can be
> *deterministically wrong*. The hallucination rate must be **measured empirically**
> in this benchmark before any quantitative claim is reported.

---

### R3 — Dissemination & Output

> R1 + R2 converge here: results are published as artifacts separate from the software.

- [ ] Publish open validation dataset (Zenodo DOI, separate from software)
- [ ] Draft technical paper / preprint (arXiv)

> **Open data strategy & license gate:**
> - Publish the **derived ESM parametric dataset** (CC-BY-4.0) as a re-distributable
>   Zenodo artifact with its own DOI, separate from the software.
> - **License re-verification step before publishing ANY derived data:** re-check the
>   current ITACA/ESM license terms and update `CITATION.cff` at release time (ITACA is
>   CC-BY-NC-ND-4.0 and forbids redistribution of derived waveforms).

---

## Future Horizon — Cloud Infrastructure & Real-Time Auto-Scaling

Production-grade cloud platform behind the alert pipeline: the MQTT/REST/AI stack of v1.x–v2.2 runs as containerized workloads on Kubernetes, fully provisioned as **Infrastructure-as-Code** with Terraform. The control plane elastically scales with the number of deployed sensors and with real-time alert bursts.

> Post-research horizon (after v2.2.0 / paper). Not blocking for the thesis; it targets the operational release of the system.

**Infrastructure-as-Code (Terraform):**
- Declarative provisioning of the cloud provider resources (managed Kubernetes cluster, VPC, node pools, networking) in versioned modules
- State management and drift detection for reproducible, auditable deployments

**Orchestration (Kubernetes):**
- Containerized deployment of the MQTT broker, AI report worker, REST control plane and dashboard
- Native autoscaling (Horizontal Pod Autoscaler / cluster autoscaler) driven by MQTT ingestion rate and CPU/memory
- Real-time elastic burst handling: alert spikes scale up workers (AI reports) and event queues; quiet periods scale to zero
- Rolling updates, health probes and self-healing for continuous availability

**Delivery & observability:**
- GitOps / CI/CD pipeline applying Terraform and Helm charts
- Monitoring and alerting for the cluster itself (resource saturation, autoscaling events)

### Performance & scaling engineering (post-paper, not needed at current scale)

- **Kafka / Redpanda as the central ingestion buffer (millions-class)** — replaces Redis Streams as the durable, replayable backbone once sustained ingestion exceeds what a single Redis node can buffer. The v2.3.0 consumer interface (`src/ingest.py`) is deliberately transport-agnostic: `enqueue_reading` / `read_batch` / `ack` / `recover_pending` are re-pointable so a Kafka-backed implementation can slot in without touching the worker. Also unlocks partitions-per-sensor ordering and backfill reprocessing for the triangulation engine (v2.1).
- **ClickHouse for cold-path analytics** — move long-range dashboards / multi-node correlation queries (epicenter triangulation, swarm clustering) off the operational Postgres node onto a columnar store with a Kafka connector. Cold reads never contend with the ingestion hot path; TimescaleDB continuous aggregates keep serving the real-time dashboard.
- **Non-blocking MQTT-Bridge refactor** — `aiomqtt` + async push to Redis (or `httpx`/`aiohttp`)
  to make the bridge relay fully non-blocking. *Partially superseded by v2.3.0: the ingestion
  endpoint is now an O(1) stream append, so the HTTP-proxying bridge is no longer the DB
  bottleneck; direct MQTT→stream still removes the HTTP hop and is the documented next step.*
- **Rust ingestion microservice (Axum) + ECDSA verification via PyO3** — the hybrid path:
  keep FastAPI/PostGIS/Ollama, move only the CPU-bound signature verification (P-256/SHA-256)
  to native speed; a dedicated Axum ingestion endpoint can later absorb `POST /readings/`.
- **Local MQTT broker (`mosquitto`) as the default alert path** — makes the R2 "local-first
  resilience" claim real; explicitly note HiveMQ Cloud as the current WAN dependency.
- **Load-test on rented infrastructure (e.g. AWS), one-off** — not GitHub Actions (hardware
  limits); results published as static charts in the paper.

---

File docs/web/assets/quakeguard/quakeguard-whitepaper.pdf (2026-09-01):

# QuakeGuard

## Distributed Earthquake Early Warning System

### Technical Architecture & Protocol Specification

Release: v2.0.0 (Hybrid Infrastructure & GNSS Automation)

Core Maintainers: @GiZano, @riccardo0731

QuakeGuard v2.0.0 - Technical Architecture

## Table of Contents

## 1. System Architecture & Overview

QuakeGuard is a distributed, high-throughput backend system designed for the real-time ingestion, cryptographic validation, and processing of seismic data from IoT devices[cite: 1]. It serves as the core infrastructure for an Earthquake Early Warning (EEW) system[cite: 1]. The architecture is explicitly designed to handle high-concurrency event firehosing during seismic swarms while maintaining strict security boundaries.

### 1.1. High-Level Topology

The infrastructure is decoupled into three primary tiers:

- Edge Layer (IoT): Composed of ESP32-C3 SuperMini microcontrollers interfaced with ADXL345 digital accelerometers[cite: 1]. These nodes execute on-device Digital Signal Processing (DSP) using the STA/LTA (Short Term Average / Long Term Average) algorithm[cite: 1].
- Core Backend & Processing: A polyglot backend architecture utilizing FastAPI (Python) as the API gateway[cite: 1]. Validated data is asynchronously offloaded to a Redis Stream (readings:stream) and consumed by horizontally-scalable background workers via consumer groups[cite: 1]. The workers persist time-series data into a PostgreSQL/PostGIS database (provisioned as a TimescaleDB hypertable) and trigger area-scoped alerts via Redis Pub/Sub[cite: 1].
- Client Presentation Layer: A React Native (Expo) mobile application providing users with real-time seismograph telemetry and instantaneous critical event notifications delivered through WebSockets and native push notifications[cite: 1].

### 1.2. Data Plane and Control Plane

Following the v1.1.0 cloud migration, the architecture strictly separates the data and control pipelines:

- Data Plane (Telemetry): Flows exclusively through a HiveMQ Cloud Serverless broker on port 8883[cite: 1]. Communication is fully authenticated and TLS-encrypted[cite: 1]. A Python-based MQTT bridge (mqtt_subscriber.py) subscribes to the quakeguard/telemetry topic and forwards payloads to the internal FastAPI ingestion pipeline via HTTP POST[cite: 1].
- Control Plane (Provisioning & Management): Device onboarding, cryptographic handshakes, and REST retrieval operations are routed through an HTTPS tunnel to the FastAPI endpoints (e.g., / devices/register)[cite: 1]. In development the tunnel is a Cloudflare quick tunnel (cloudflared tunnel --url http://localhost:8000); production should use a real HTTPS domain. The ngrok free-tier edge is not used because its bot-protection terminates ESP-IDF (mbedTLS) TLS handshakes via JA3 fingerprinting before any HTTP header can be read, so IoT clients never reach the backend.

### 1.3. Key Design Principles

- Zero-Trust Security: Every telemetry payload must be cryptographically signed using an ECDSA (NIST256p) private key stored securely in the ESP32′s Non-Volatile Storage (NVS)[cite: 1]. The backend validates these signatures (SHA-256) and device timestamps to prevent spoofing and replay attacks[cite: 1].
- Asynchronous Decoupling: The ingestion API is strictly non-blocking. Validated payloads are immediately pushed to the Redis Stream, allowing the gateway to acknowledge the IoT device in milliseconds while background workers handle heavy database transactions and magnitude estimations[cite: 1].
- Spatial Awareness: Leveraging PostGIS, the system automatically assigns newly provisioned sensors to geographic zones using polygon containment[cite: 1]. A geohash-based Redis index (zoneindex:<geohash>) pre-computed at seed time provides a fast-path for coordinate-to-zone resolution, with PostGIS ST_Contains as the authoritative fallback[cite: 1]. This enables targeted, geographically bounded alert broadcasting with per-area cooldowns[cite: 1].

## 2. Hardware & Edge Computing (ESP32-C3)

The edge layer of QuakeGuard is designed to operate on resource-constrained microcontrollers, specifically targeting the ESP32-C3 SuperMini platform (RISC-V architecture)[cite: 1]. The node interfaces with an ADXL345 digital accelerometer to acquire, filter, and analyze seismic data locally, transmitting only cryptographically signed anomaly reports to conserve bandwidth[cite: 1].

### 2.1. Hardware Configuration & Interfacing

Due to the specific physical layout of the ESP32-C3 SuperMini, the I2C bus is software-mapped to nonstandard GPIO pins[cite: 1]:
- SDA (Data): Mapped to GPIO 7, requiring internal pull-up resistors[cite: 1].
- SCL (Clock): Mapped to GPIO 8, requiring internal pull-up resistors[cite: 1].
- Power Constraints: The ADXL345 is powered strictly via the 3.3V rail; applying 5V will result in immediate hardware damage[cite: 1].

The sensor operates at a 100Hz sampling rate (ADXL345_DATARATE_100_HZ) with a measurement range of pm16G (ADXL345_RANGE_16_G)[cite: 1]. To prevent I2C bus race conditions during startup, the sensor object is instantiated dynamically in memory only after the hardware bus is fully stabilized[cite: 1].

### 2.2. Digital Signal Processing (DSP) & Calibration Pipeline

Raw acceleration data undergoes multiple stages of local processing and calibration before being evaluated:
- Static Offset Calibration: Upon boot, the sensor performs a static 100-sample averaging sequence while the node is at rest. The calculated positional offsets are written directly to the ADXL345 hardware registers (OFSX, OFSY, OFSZ), inherently zeroing the sensor at the hardware level and removing physical mounting biases[cite: 1].
- High-Pass Filter (HPF): A digital filter (HPF_ALPHA = 0.9f) isolates the dynamic vibration data by subtracting the static DC component (Earth’s gravity, approx. 9.81 m
s

2 )[cite: 1].
- Noise Gate: Micro-vibrations below the empirical threshold of 0.04G are clamped to zero to prevent false positives generated by electrical noise[cite: 1].
- Dropout Protection: The firmware automatically drops frames reporting near-zero absolute acceleration (less than 2.0 m
s

2 prior to filtering), effectively mitigating corrupted readings caused by temporary I2C wire disconnects[cite: 1].

### 2.3. STA/LTA Seismic Detection Algorithm

QuakeGuard implements the industry-standard Short-Term Average / Long-Term Average (STA/LTA) algorithm[cite: 1]. The implementation utilizes a custom, memory-efficient RingBuffer template class in C++ to maintain rolling sums, allowing O(1) average calculations[cite: 1].
- Short-Term Window (STA): 100 samples (1 second of telemetry), representing the immediate seismic transient[cite: 1].
- Long-Term Window (LTA): 1000 samples (10 seconds of telemetry), representing the background noise floor[cite: 1].
- Trigger Condition: An earthquake is registered when the STA/LTA ratio exceeds 1.8f, provided the STA absolute value is also above the noise floor[cite: 1].

### 2.4. FreeRTOS Task Architecture

The firmware utilizes FreeRTOS to decouple time-critical sensor acquisition from network latency[cite: 1].
- sensorTask: Pinned to a high priority, it wakes exactly every 10ms to poll the ADXL345 and execute the DSP pipeline[cite: 1]. Upon detecting a seismic event, it pushes a SeismicEvent struct to the
eventQueue[cite: 1].
- networkTask: Operates asynchronously at a lower priority[cite: 1]. It consumes the eventQueue, synchronizes the event timestamp via NTP (pool.ntp.org), signs the payload, and dispatches the MQTT message[cite: 1]. This design ensures that network blocking or Wi-Fi reconnects never halt the continuous monitoring of the accelerometer[cite: 1].
- gnssTask (optional): When the GNSS subsystem is compiled in, a dedicated task (priority 2) continuously feeds NMEA frames into the parser so the coordinate pipeline is always live[cite: 1].

### 2.5. Zero-Trust Serial Fallback (v1.2.2)

Since v1.2.2 the edge node tolerates complete MQTT/WiFi loss without losing cryptographicallyattested telemetry[cite: 1]. The networkTask becomes a first-available-path dispatcher: MQTT → USB
CDC Serial → Retention Ring[cite: 1].
- Framing: SerialFallback.h builds [QG:FB]{...} frames whose JSON is byte-identical to the MQTT payload (value, sensor_id, device_timestamp, signature_hex)[cite: 1]. The marker lets the host bridge filter CDC noise without parsing every line[cite: 1].
- Host-aware routing: Serial.isConnected() (HWCDC, ARDUINO_USB_CDC_ON_BOOT=1) distinguishes a real USB host from a power-only charger; with no host the event is retained rather than written to a dead port[cite: 1]. The pure routing function decidePath(mqttReachable, usbHostPresent, timeValid) is shared between the firmware and the host SIL test suite[cite: 1].
- Retention & drain: A bounded RetentionRing<100> holds events in FIFO order (oldest overwritten on overflow). When a path becomes reachable the ring is drained in order; each retained event is re-signed with the current wall time at drain so the backend ±300 s anti-replay window accepts the retransmission[cite: 1].
- Offline wall clock: NTP is opportunistic (pool.ntp.org via configTime). At the first successful sync the firmware anchors epochAtSync + millis(); subsequent timestamps remain valid after WiFi drops and no frame is emitted before timeValid[cite: 1].
- Host bridge: firmware/tools/serial_bridge.py reads /dev/ttyACM0, filters [QG:FB] lines via parse_frame(), validates the ingestion URL against SSRF (_validate_api_url), and POSTs to / readings/ with X-API-Key — the same forwarding path as mqtt_subscriber.py[cite: 1]. A
test_serial_fallback.cpp suite covers buildSerialFrame, decidePath and ring semantics on the host[cite: 1].

### 2.6. Diagnostic LED Indicators

The ESP32-C3 firmware drives two diagnostic LEDs to provide immediate visual feedback of the node’s operational state without requiring a serial monitor[cite: 1]:
- Boot Test: Upon power-up, both the Blue and Red LEDs blink simultaneously twice to verify wiring integrity before the FreeRTOS tasks start[cite: 1].
- Solid Blue: The node is fully online, with both Wi-Fi connected and an active MQTT session established with the broker[cite: 1].
- Single-Blinking Blue: Wi-Fi is connected, but the MQTT broker is unreachable. The node is attempting opportunistic reconnection[cite: 1].

- Double-Blinking Blue: Wi-Fi connection is lost. The node is actively scanning and attempting to reassociate with the AP[cite: 1].
- Solid Red (3-second pulse): A seismic event (earthquake) was successfully detected by the STA/LTA algorithm. This overrides any blue LED state[cite: 1].
- Serial Fallback Indication: If a seismic event occurs while the Blue LED is blinking (no MQTT), the Red LED will still pulse. This specific combination (Blinking Blue + Solid Red pulse) visually confirms to the operator that the node has fallen back to writing the cryptographically-signed event to the USB CDC Serial port or parking it in the Retention Ring[cite: 1].

### 2.7. PCB Design & Physical Assembly (v2.0.0)

With the v2.0.0 milestone, the QuakeGuard hardware has matured from a breadboard prototype to a custom Printed Circuit Board (PCB), designed in KiCad[cite: 1]. The hardware/ directory contains the complete schematic, PCB layout, and manufacturing Gerber files.
- Layout Integration: The PCB provides dedicated footprints for the ESP32-C3 SuperMini, the ADXL345 accelerometer (powered correctly at 3.3V), and the optional u-blox GNSS receiver[cite: 1].
- Signal Integrity: The I2C lines (SDA on GPIO 7, SCL on GPIO 8) include proper hardware pull-up resistors on the PCB to guarantee stable communication at 100Hz without relying on the weak internal MCU pull-ups[cite: 1].
- External Interfacing: A J4 header exposes the GNSS UART lines (RX GPIO 5, TX GPIO 4, PPS GPIO 2) and power rails, allowing modular connection of the GPS antenna for accurate time synchronization and epicentral triangulation[cite: 1].

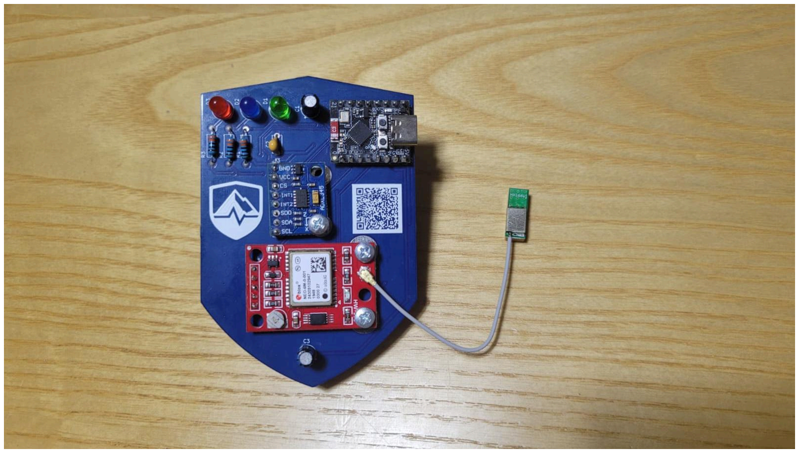
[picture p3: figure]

Figure 1: The QuakeGuard v2.0.0 fully assembled PCB, featuring the ESP32-C3 SuperMini, the ADXL345 accelerometer, and the u-blox GNSS module soldered into their dedicated footprints.

### 2.8. GNSS Subsystem & NTP Discipline (v2.0.0)

Since v1.2.1 the firmware is GNSS-ready: an optional module parses NMEA data from a u-blox / NEO-6M / NEO-M8N receiver over the secondary UART (RX GPIO 5, TX GPIO 4, 9600 baud on the JLCPCB — J4-3→GPIO5, J4-4→GPIO4, J4-5→GPIO2 PPS for v2.0.0) at 9600 baud[cite: 1]. The module is compiled only when GNSS_ENABLED=1 is present in esp32_config.env, so the default build stays hermetic and pulls no TinyGPSPlus dependency[cite: 1]. Defaults in GnssModule.h are RX

5 / TX 4 to match the fabricated PCB; they remain overridable via GPS_SERIAL_RX_PIN/TX_PIN in
esp32_config.env through extra_script.py[cite: 1].
- Last-Known Fix Persistence: Every reliable fix is saved into NVS (namespace quake-gnss, at most once per 60 seconds to limit flash wear)[cite: 1]. Provisioning therefore reports real coordinates even before the first fix after a cold boot[cite: 1].
- Staleness Handling: A live fix older than 10 seconds is treated as stale and the firmware falls back to the last-known value[cite: 1].
- Provisioning Integration: During /devices/register, the node reports the live GNSS fix when available, else the last-known-from-NVS fix; when neither exists it uses GNSS_FALLBACK_LAT/LON from esp32_config.env if defined (indoor testing), otherwise coordinates are omitted so the backend can assign the zone once placed[cite: 1].
- NTP + PPS Discipline: The core feature of v2.0.0. The pulse-per-second (PPS) hardware interrupt (GPIO 2) records the precise millis() at the start of each UTC second. The networkTask synchronizes via NTP and then disciplines the internal epochAtSync directly to the last PPS interrupt, ensuring stratum-1-like millisecond precision for all seismic telemetry[cite: 1].

### 2.9. Software-in-the-Loop (SIL) Validation

To ensure the theoretical STA/LTA model translates correctly to the real world, the QuakeGuard firmware edge core (DetectionCore.h) is tested headlessly against a Python-based Software-in-the-Loop pipeline.
- Open Data Integration: The pipeline dynamically queries the public INGV FDSN web service via ObsPy, fetching raw waveforms from the IV and MN open networks for specific historical baselines (e.g., L’Aquila 2009, Amatrice 2016, Emilia 2012)[cite: 1].
- DSP Simulation: Raw data is deconvolved to physical acceleration ( m
s

2 ), causal bandpass-filtered (1-20 Hz), and resampled to exactly 100 Hz to simulate the ADXL345 physical output[cite: 1].
- Algorithmic Certification: The multidimensional calibration sweep proves the current STA/LTA threshold (ratio=2.4, floor=0.02G) yields a theoretical 80% True Positive Rate with a 0.0% False Alarm Rate against the validation dataset, demonstrating maximal rejection of distant micro-seismicity (like Salizzole at 100km) while triggering on near-fault impulses within 3 seconds of the P-wave arrival[cite: 1].

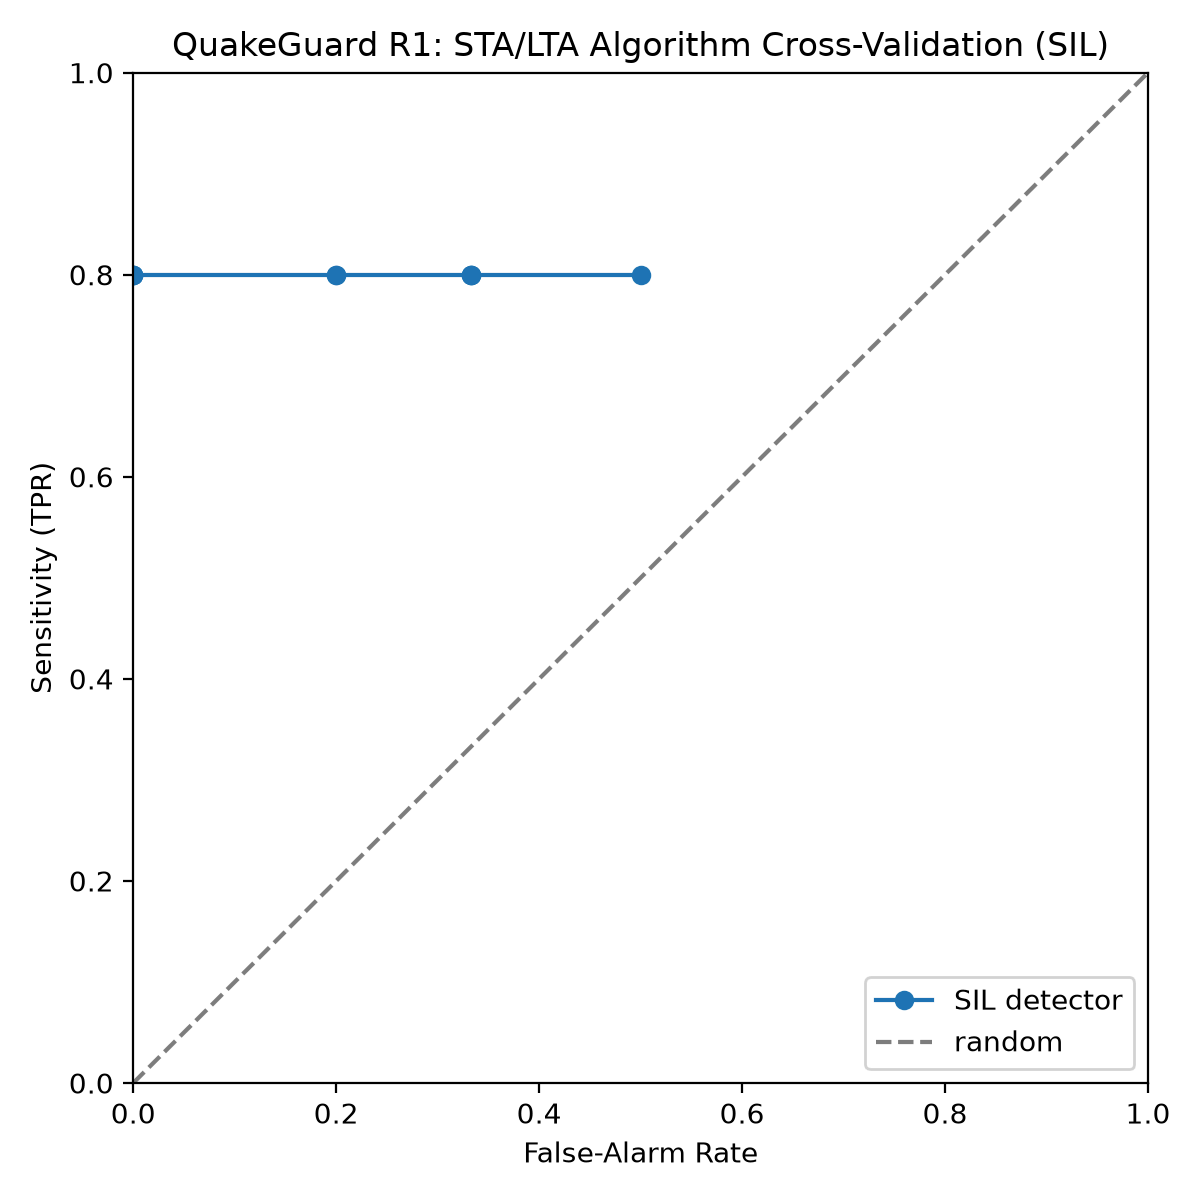
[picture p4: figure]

Figure 2: Receiver Operating Characteristic (ROC) curve of the edge STA/LTA algorithm. The curve reaches a hard upper bound at 0.8 (80%) True Positive Rate (Sensitivity). This limit represents a highly desirable geophysical outcome: 4 out of 5 historical events are perfectly identified without any false alarms (FAR = 0.0), while the 5th event (a weak micro-seismicity recorded at >100km distance) correctly fails to trigger the algorithm, proving the firmware’s robustness against distant noise.

## 3. Cryptographic Security & Provisioning

QuakeGuard implements a Zero-Trust security model for its IoT edge nodes[cite: 1]. To prevent rogue devices from injecting false seismic data (spoofing) or re-transmitting old events (replay attacks), the system relies on asymmetric cryptography and strict temporal validation[cite: 1].

### 3.1. Cryptographic Identity (ECDSA)

Upon its first boot, the ESP32-C3 utilizes the mbedtls library to generate a unique Elliptic Curve Digital Signature Algorithm (ECDSA) key pair using the NIST P-256 curve (secp256r1)[cite: 1].
- Private Key: Stored securely and permanently in the device’s Non-Volatile Storage (NVS)[cite: 1]. It never leaves the device and is used exclusively to sign outgoing telemetry[cite: 1].
- Public Key: Extracted in DER format, converted to a hexadecimal string, and acts as the unforgeable cryptographic identity of the sensor within the backend database[cite: 1].

### 3.2. Automated Provisioning Handshake

Before transmitting any seismic data, an unregistered sensor must complete an automated handshake with the Control Plane[cite: 1]:
1. The device sends a POST request to the /devices/register endpoint, providing its generated public_key_hex, MAC address, GPS coordinates, and a hardcoded ENROLLMENT_TOKEN[cite: 1].
2. The backend validates the factory enrollment token to ensure the device is authorized to join the network[cite: 1].
3. Using a geohash-based Redis fast-path index with an authoritative PostGIS fallback (ST_Contains), the backend spatially evaluates the provided GPS coordinates against the predefined zones and assigns the sensor to the smallest containing geographic polygon[cite: 1]. When a GNSS module is attached, the coordinates are the live fix (or the last-known fix persisted in NVS); otherwise the node reports a hardcoded placeholder until provisioned in place[cite: 1].
4. A unique sensor_id is returned to the device, which saves it to NVS for all future communications[cite: 1].

### 3.3. Payload Authentication & Integrity

When a seismic event triggers the DSP pipeline, the firmware constructs a string containing the measured magnitude and the current timestamp (format: value:timestamp)[cite: 1]. Under normal operation the timestamp is the NTP-synchronized wall time; when the serial fallback drains the retention ring it is the software wall clock epochAtSync + millis() at drain time, and the payload is re-signed with the current time so the backend’s replay window accepts it[cite: 1]. This string is hashed via SHA-256 and signed with the device’s private key[cite: 1].

The resulting JSON payload includes the data, the timestamp, and the signature_hex — identical on the MQTT and serial data planes ([QG:FB] frames carry the same JSON behind the marker)[cite: 1]. Once received by the backend, the validate_iot_payload dependency pipeline enforces four security gates[cite: 1]:
- API Key Verification: Validates the X-API-Key header using a constant-time comparison (hmac.compare_digest) to prevent timing attacks[cite: 1].
- Sensor Status: Confirms the sensor ID exists and is marked as active in the PostgreSQL database[cite: 1].
- Anti-Replay Protection: Compares the device’s timestamp against the server’s UTC time. Payloads older than a 300-second threshold are outright rejected with a 403 Forbidden error[cite: 1].
- Signature Verification: The backend utilizes the Python cryptography library to verify the ECDSA signature against the public key associated with that sensor[cite: 1]. The implementation robustly supports both DER-encoded signatures (native to MbedTLS) and raw concatenated r ‖ s signatures[cite: 1].

## 4. Data Plane & Message Broker (MQTT)

With the release of v1.1.0, QuakeGuard migrated its Data Plane from a local, cleartext MQTT architecture to a robust, cloud-based infrastructure[cite: 1]. This decoupling ensures that high-frequency seismic telemetry is handled by a dedicated message broker optimized for IoT, freeing the edge nodes from the overhead of HTTP round-trips[cite: 1].

### 4.1. HiveMQ Cloud Infrastructure

The core of the Data Plane is a HiveMQ Cloud Serverless broker[cite: 1].

- Encrypted Transport: All telemetry is transmitted over port 8883 using strict Transport Layer Security (TLS)[cite: 1].
- Authentication: Anonymous access (allow_anonymous true) has been deprecated[cite: 1]. The broker now requires explicit MQTT_USERNAME and MQTT_PASSWORD credentials for every connection[cite: 1].
- Topic Topology: All valid seismic anomalies are published to the unified quakeguard/telemetry topic[cite: 1].

### 4.2. Edge Node Implementation (Firmware)

On the ESP32-C3, the networkTask handles the MQTT transmission asynchronously[cite: 1].
- To | support | TLS | on | resource-constrained | hardware, | the | firmware | utilizes
WiFiClientSecure::setInsecure() combined with the PubSubClient library[cite: 1].
- When a SeismicEvent is popped from the FreeRTOS queue, the firmware packages the JSON and fires the payload to the broker[cite: 1]. This “fire-and-forget” approach reduces transmission blocking time to milliseconds, ensuring the sensorTask is never starved of CPU cycles[cite: 1].

### 4.3. Host Serial Bridge — Second Ingestion Path (v1.2.2)

When MQTT is unreachable the host can collect [QG:FB] frames over USB CDC and forward them to the same ingestion pipeline. firmware/tools/serial_bridge.py tails /dev/ttyACM0 (default SERIAL_PORT), filters lines starting with [QG:FB], parses the JSON suffix and POSTs it to / readings/ with X-API-Key — identical security gates as the MQTT bridge[cite: 1]. URL validation (_validate_api_url) restricts schemes to http/https, rejects embedded credentials and non-alphanumeric hostnames (SSRF guard), and parse_frame() returns None on boot-log noise so the reader never crashes on malformed lines[cite: 1]. A dry-run and --stdin mode plus the iot-ci.yml parser smoke test keep the bridge testable without hardware[cite: 1].

### 4.4. Internal MQTT Bridge Service

To securely ingest the MQTT data into the backend without exposing the FastAPI worker directly to the public internet, QuakeGuard employs a dedicated bridging microservice (mqtt_subscriber.py)[cite: 1].
- Protocol Bridging: Written in Python using the paho.mqtt.client (v2 API), the bridge acts as an authorized subscriber to the HiveMQ broker[cite: 1]. It initiates a secure connection using
client.tls_set(cert_reqs=ssl.CERT_REQUIRED)[cite: 1].
- Internal Routing: Upon receiving a message on quakeguard/telemetry, the bridge wraps the payload and forwards it to the internal FastAPI ingestion endpoint (/readings/) via a standard HTTP POST request[cite: 1].
- Security Injection: The bridge injects the X-API-Key header into the HTTP request, acting as a trusted proxy between the external MQTT cloud and the internal Docker network[cite: 1]. If the API rejects the payload (e.g., due to an invalid cryptographic signature), the bridge logs the failure without crashing[cite: 1].

## 5. Backend Services & Event Processing

The QuakeGuard backend is engineered to handle massive telemetry spikes (firehosing) typical of seismic swarms[cite: 1]. To achieve this, the architecture strictly decouples data ingestion from data processing using a producer-consumer pattern mediated by Redis[cite: 1].

### 5.1. API Gateway & Asynchronous Ingestion

The primary entry point is a FastAPI application running behind an ASGI server (Uvicorn) within a Docker container[cite: 1].

- Rate Limiting: To protect against Denial of Service (DoS) and buggy edge nodes, the ingestion endpoint (/readings/) utilizes a sliding-window rate limiter backed by Redis sorted sets (ZADD, ZREMRANGEBYSCORE), restricting traffic to 50 requests per second per IP[cite: 1].
- Queue Offloading: Once a payload passes the strict cryptographic validation pipeline, the API does not block to perform database writes[cite: 1]. Instead, it immediately serializes the event and pushes it to the ingest stream via an XADD command, returning an HTTP 202 Accepted to the bridge in milliseconds[cite: 1].

### 5.2. Redis Streams Ingestion Substrate

Since v1.2.1 the telemetry queue is a Redis Stream (default readings:stream), not a plain List. Lists cannot support consumer groups, so the previous single-worker BRPOP design bounded scale to one process and could lose a message on a crash mid-read[cite: 1]. Streams fix both concerns:
- Horizontal Scale: Any number of producers XADD to the stream (HTTP API, MQTT bridge, …). Any number of worker processes consume with XREADGROUP; Redis balances deliveries across the group, so capacity is added with docker compose scale worker=N[cite: 1].
- At-Least-Once Delivery: XAUTOCLAIM reclaims entries left pending by crashed consumers, so no message is lost across worker restarts[cite: 1].
- Poisoned-Message Isolation: Unparseable or fatally-failing messages are parked on a Dead Letter Stream (default readings:dlq) and acknowledged, so a poisoned heartbeat can never stall the group[cite: 1].
- Right-Sized Backpressure: The stream is capped with MAXLEN ~200000 (approximate trimming); consumers read in batches of up to 64 messages with a 500ms block, and every batch is flushed in a single database transaction[cite: 1].
- Logical Multi-Tenancy: Every key (stream, group, DLQ, consumer prefix) is re-pointable via environment variables, so a single backend can serve multiple logical regions simply by renaming the stream[cite: 1].

### 5.3. Background Worker & Persistence

A decoupled Python worker (worker.py) runs in a continuous loop, consuming the readings:stream via a blocking XREADGROUP and reclaiming stale pending entries with XAUTOCLAIM[cite: 1].
- Database Pooling: The worker and the API share a heavily optimized SQLAlchemy connection pool targeting a PostgreSQL database[cite: 1]. The engine is configured with aggressive pooling parameters (pool_size, max_overflow) to handle high-concurrency load testing without queue exhaustion[cite: 1].
- Batch Atomicity: A whole stream batch is staged in-memory and persisted with a single db.commit(); only cooldown locks are taken per-event (atomic Redis SET NX). On a database error the entire batch is routed to the DLQ rather than partially applied[cite: 1].

### 5.4. TimescaleDB Hypertable

The readings table is provisioned as a TimescaleDB hypertable partitioned on recorded_at, so time-series chunks stay small and pruning stays efficient even under firehosing[cite: 1]. The provisioning module (timescale.py) applies the DDL best-effort and idempotently: if the connected image lacks the extension it fails closed with a warning, keeping the standard PostGIS image compatible for CI while production uses the unified TimescaleDB+PostGIS image[cite: 1]. On newer TimescaleDB releases (2.13+/3.x) the hypertable is additionally configured for columnstore access[cite: 1]. The Reading model uses a composite primary key (id, recorded_at) because TimescaleDB requires the partitioning column to be part of every unique key[cite: 1].

### 5.5. Geographic Zoning & Zone-Scoped Data

v1.2.1 makes PostGIS zones the source of truth for the network topology[cite: 1]:
- Zone Management: GET /zones lists the monitored polygons; POST /zones/ creates one[cite: 1].
- Spatial Auto-Assignment: On provisioning, resolve_zone maps a device’s coordinates to the smallest containing polygon. It first consults a Redis fast-path index (zoneindex:<geohash> → set of zone ids, precision 3), and only on a cache miss or an ambiguous multi-zone match does it run the authoritative PostGIS ST_Contains query ordered by polygon area. The cache is purely an optimization and can never assign the wrong zone[cite: 1].
- Zone Detection: GET /zones/locate?latitude=...&longitude=... resolves an arbitrary GPS fix into its containing monitored zone (404 when outside any polygon), powering the mobile “Detect my zone” flow[cite: 1].
- Zone-Scoped Retrieval: GET /zones/{zone_id}/readings (live per-zone telemetry for the per-zone seismograph), DELETE /zones/{zone_id}/readings (operational purge), and GET /zones/ {zone_id}/alerts (confirmed alerts raised for a single area)[cite: 1].

### 5.6. Magnitude Estimation & Per-Area Deduplication

For every processed event, the worker performs a physical magnitude estimation based on a MyShakestyle MEMS calibration approach[cite: 1]. The raw Peak Ground Acceleration (PGA) is converted using the formula[cite: 1]:

MIoT = log10

(PGAcalib) + b

Where PGAcalib accounts for the ADXL345 scale and hardware calibration constant (K_CALIBRATION = 1.6), and b is an empirical offset (B_OFFSET = 3.0)[cite: 1]. The same normalization is shared with the mobile client so the app and the backend report identical magnitudes[cite: 1].

- Thresholding: If the estimated magnitude reaches or exceeds the critical threshold of 4.5, the worker triggers an Alert entity[cite: 1].
- Per-Area Cooldown: During a real earthquake, dozens of sensors in the same region will breach the threshold simultaneously. To prevent notification spam, the worker uses a Redis atomic check-and-set operation (SET nx=True, ex=60) keyed by the area — the reading’s geohash region (precision 4, 39 x 19 km) when coordinates are present, else the zone — enforcing a strict 60-second cooldown per geographic area rather than globally[cite: 1]. Reading.lat/lon are captured at ingestion precisely to enable this fragmentation and future spatial correlation[cite: 1].
- Outbox Pattern: Only the first worker process that successfully acquires the Redis lock will persist the Alert to PostgreSQL and publish the JSON payload to the quake_alerts Redis Pub/Sub channel[cite: 1].

## 6. Mobile Client & Live Telemetry

The client-side presentation layer of QuakeGuard is a cross-platform mobile application built with React Native and the Expo framework[cite: 1]. It serves as the primary interface for users to monitor the seismic network and receive instantaneous Earthquake Early Warning (EEW) notifications[cite: 1].

### 6.1. Real-Time Alerting (WebSockets)

To guarantee sub-second delivery of critical alerts, the mobile app maintains a persistent, full-duplex connection to the backend via WebSockets[cite: 1].
- Connection Management: The WebSocketContext initializes a connection to the /ws/alerts endpoint, authenticating via a secure query parameter (MOBILE_WS_TOKEN)[cite: 1]. The client implements an exponential backoff strategy for automatic reconnections up to a maximum delay of 30 seconds[cite: 1].
- Native Haptics & Notifications: When the WebSocket receives a payload tagged as "CRITICAL", the application bypasses standard UI updates and immediately triggers native hardware APIs[cite: 1]. It executes an SOS vibration pattern (Vibration.vibrate) and schedules a high-priority system push notification using expo-notifications (AndroidImportance.MAX), ensuring the user is alerted even if the app is in the background[cite: 1].

### 6.2. Telemetry Visualization & State

The dashboard provides a live view of the network’s health and recent seismic activity, relying on a robust state management architecture[cite: 1].
- Data Fetching (TanStack Query): Standard REST operations, such as fetching the active sensor list and the latest telemetry points (/readings/), are managed by React Query[cite: 1]. This provides automatic caching, background refetching (every 2 seconds for live readings), and loading state management[cite: 1].
- Per-Zone Live Seismograph: Since v1.2.1 the dashboard no longer mixes network-wide telemetry. A horizontal strip of zone chips (ZoneSelector) lets the operator pick a monitored polygon, and
a VictoryChart (victory-native) renders that zone’s live trace from GET /zones/{zone_id}/ readings?limit=60[cite: 1]. The trace is anchored to the wall clock: a 60-sample / 30-second sliding window that naturally drops stale readings, uses a linear MAG scale (MIN 3.5 / MED 4.0 / ALTO
4.5) with the axis pinned left, and always renders inside the plot[cite: 1]. Raw Z-axis acceleration is converted to magnitude with the same normalization used by the backend[cite: 1].
- Geospatial Map: The react-native-maps library maps the network topology, displaying custom markers for each sensor based on their exact PostGIS coordinates and coloring them according to their active/offline status[cite: 1].

### 6.3. GPS Zone Detection & Alert Scoping

The Settings screen ships a “Detect my zone via GPS” action (DETECT)[cite: 1].
- Flow: expo-location requests foreground permission and captures a balanced-accuracy fix, then calls GET /zones/locate?latitude=...&longitude=... to resolve the fix into its containing monitored zone[cite: 1].
- Outcome: | The | resolved | zone | becomes | the | operator’s | homeZoneId | (persisted | in
usePreferencesStore). Incoming CRITICAL alerts are gated by ringsForZone(): they ring, vibrate, and notify only when they match the home zone (or when no home zone is set — “ALL REGIONS”) [cite: 1].
- Error Handling: A 404 (“coordinates outside any monitored polygon”) prompts “Outside monitored area”; manual zone chips remain as a fallback[cite: 1].

### 6.4. Dual Theme (MIC / RESEARCH Mode)

The appearance layer ships two operator modes toggled from Settings[cite: 1]:
- MIC MODE (dark): themeMode: 'dark' — a zinc-950 tactical palette with emerald/amber/red semantic accents[cite: 1].
- RESEARCH MODE (light): themeMode: 'light' — a slate-50 “scientific paper” palette for lab analysis[cite: 1].

The active theme propagates through useAppTheme() to every screen, the seismograph’s Victory theme, the tab bar, and the Google Map styles (Android)[cite: 1].

### 6.5. Resilience and Global State (Zustand)

Global application state, including alert history and user preferences, is managed using Zustand[cite: 1].
- Alert Store: The useAlertStore maintains a rolling history of the 10 most recent alerts, persisting them for the dashboard’s activity log[cite: 1]. Each row can embed the matching AI Emergency Report (summary + per-item recommendations), and a dedicated AiReportCard renders the latest report banner inline[cite: 1].
- Siren Audio: On a matching CRITICAL alert the app plays a civil-defense siren (expo-audio, looping the bundled alarm.wav for a bounded 15-second window, auto-stopped and non-overlapping) alongside the native SOS Vibration.vibrate pattern and a MAX-priority push notification[cite: 1].
- Offline Mode: The usePreferencesStore controls a user-toggled “Offline Mode”[cite: 1]. When activated, the application cleanly and intentionally closes the active WebSocket connection and disables all React Query background polling (enabled: !isOfflineMode), effectively halting network traffic and conserving battery life during maintenance or low-power situations[cite: 1].

## 7. Deployment & Operations Guide

This section outlines the procedures for provisioning the QuakeGuard infrastructure in a local or development environment.

### 7.1. Prerequisites

To orchestrate the full stack, the host machine must have the following dependencies installed:
- Backend: Docker Engine and Docker Compose.
- Edge (IoT): Visual Studio Code with the PlatformIO IDE extension.
- Mobile: Node.js (v18+) and the Expo Go application installed on a physical smartphone.

### 7.2. Backend Provisioning

The backend services (PostgreSQL, TimescaleDB, Redis, FastAPI, Worker, AI-Worker, and MQTT Bridge) are fully containerized[cite: 1]. The system uses a Hybrid Network Architecture where the backend runs locally, while exposing an automated Cloudflare tunnel for external WAN traffic[cite: 1].

1. Navigate to the project root and launch the orchestrator:

./scripts/quakeguard_init.sh

This single command automates the entire infrastructure deployment:
1. Spawns tunnel_init.sh to negotiate a new Cloudflare HTTPS tunnel.
2. Dynamically injects the generated URL into the Mobile and Firmware .env configurations.
3. Opens a 3-split terminal window (using ptyxis or tmux) that simultaneously boots the Docker Compose backend (with the --profile ai flag for LLaMa3.2), starts the Expo bundler for the mobile client, and compiles/flashes the ESP32 firmware via PlatformIO.

### 7.3. Horizontal Worker Scaling

Because telemetry is consumed through Redis Streams consumer groups, the worker tier scales horizontally without reconfiguration: messages are balanced across the group automatically[cite: 1].

docker compose up --scale worker=N -d

### 7.4. Seismic Simulation & Stress Testing

Two companion scripts exercise the ingestion pipeline[cite: 1]:
- scripts/load_test.py — a high-concurrency End-to-End (E2E) stress test that simulates a massive seismic event through the real REST path (see the stress test section below).

- scripts/simulate_zone.py — streams synthetic per-zone readings straight through the ingestion flow, exercising the per-area cooldown fragmentation and the per-zone seismograph endpoints[cite: 1].

### 7.5. Edge Node & Mobile Client Orchestration

Because the orchestrator (quakeguard_init.sh) dynamically resolves and injects environment variables, manual configuration of the edge node and mobile client is drastically reduced.

- Edge Node: The ESP32 is automatically flashed via PlatformIO during the orchestrator’s boot sequence (pio run -t upload -t monitor). The firmware strictly requires compile-time secret injection, so rebuilding ensures the node receives the latest dynamic Cloudflare provisioning URL and Fallback Coordinates (now mapped to Milan, Italy North).
- Mobile Client: The Expo server is launched automatically. Ensure that the smartphone running Expo Go is connected to the same Local Area Network (LAN) as the host, and scan the QR code displayed in the top-right terminal window.

### 7.6. Executing the Critical Stress Test

To validate the deployment, the system includes an End-to-End (E2E) stress test that simulates a massive seismic event.

From the `backend` directory, execute:

export API_URL="http://localhost:8000" export NUM_SENSORS=150
export CONCURRENCY_LIMIT=50
python -m tests.stress_test

A successful test will conclude with the message 🏆 SYSTEM CERTIFIED, confirming that the rate limiter, security gates, and per-area cooldown locks are functioning nominally.

## 8. AI Emergency Report Service

With the release of v1.2.0, QuakeGuard introduces an on-premise AI layer that automatically generates human-readable emergency reports from confirmed seismic alerts[cite: 1]. The service is powered by a locally hosted Large Language Model (LLM) via Ollama, guaranteeing that raw telemetry — including zone coordinates and magnitude estimates — never leaves the host machine[cite: 1].

### 8.1. Privacy-First Local Inference

The AI pipeline is strictly self-contained and requires no external API keys or cloud LLM endpoints[cite: 1].

- Local Ollama Service: A dedicated ollama Docker container exposes the native Ollama API (/ api/generate) on an internal Docker network[cite: 1]. On first startup the entrypoint script (initscripts/ollama-entrypoint.sh) automatically pulls the configured model (OLLAMA_MODEL, default llama3.2:1b) before the service becomes healthy[cite: 1].
- On-Premise Isolation: Because the model runs inside the Compose network, every telemetry attribute used to compose a report stays within the host’s Docker bridge network[cite: 1]. No third-party receives the data[cite: 1].
- Model Selection: The default 1B-parameter model is intentionally small to keep CPU and RAM footprints low while remaining fast enough to generate a report in near real-time[cite: 1]. Operators may override OLLAMA_MODEL (e.g., qwen2.5:1.5b) for higher quality output[cite: 1].

### 8.2. Deterministic Report Generation

Emergency messaging must never fabricate data[cite: 1]. The AI client (ollama_client.py) therefore constrains the model with hard guarantees[cite: 1]:

- Sampling: Every request is issued with temperature: 0.0 and top_k: 1 (greedy decoding), eliminating stochastic drift between retries[cite: 1].
- Streaming Disabled: Reports are generated in a single non-streaming inference pass, simplifying parsing and validation on the backend[cite: 1].
- Strict System Prompt: The model is instructed: “You are an emergency response AI. Only use the provided JSON telemetry. Do not invent data.”[cite: 1]
- Telemetry Whitelist: The prompt is built from a fixed allowlist of fields (zone_id, zone_name, magnitude, timestamp, sensor_count), so the model can only reason about authenticated, persisted data[cite: 1].
- Failure Fallback: If the inference request fails or returns an unparseable response, the pipeline stores an explicit "AI report unavailable." message rather than attempting to guess[cite: 1].

### 8.3. Asynchronous Worker & State Machine

Report generation is fully decoupled from the alert engine via a dedicated Redis queue (ai_report_queue) and a separate consumer process (ai_report_worker.py)[cite: 1].

- Non-Blocking Enqueue: When the main worker (worker.py) persists a confirmed Alert, it creates an EmergencyReport row in PENDING state and pushes the alert context to ai_report_queue via lpush[cite: 1]. The alert pipeline is never blocked by LLM latency[cite: 1].
- State Machine: Each report transitions through a tri-state lifecycle[cite: 1]:

PENDING → COMPLETED

PENDING → FAILED

- Dedicated Consumer: The ai-worker container loops on a blocking brpop, fetches the telemetry context, invokes Ollama, and atomically flips the report state[cite: 1]. On success the worker publishes an EMERGENCY_REPORT payload to the ai_reports Redis Pub/Sub channel and commits the COMPLETED report with its summary and recommendations[cite: 1].
- Dead Letter Queue: Unrecoverable failures (missing report, persistent inference errors) push the event to ai_report_queue_dlq and mark the report FAILED[cite: 1]. The mobile app renders a “Report unavailable” badge for FAILED reports instead of showing partial or fabricated content[cite: 1].
- Graceful Shutdown: The worker traps SIGTERM/SIGINT to drain in-flight inference calls before exiting[cite: 1].

### 8.4. WebSocket Delivery

The mobile client receives reports through the existing real-time channel[cite: 1].

- Channel Subscription: The backend WebSocket broadcaster (main.py) subscribes to both quake_alerts and ai_reports, delivering each EMERGENCY_REPORT payload over the authenticated / ws/alerts socket[cite: 1].
- Correlation: The payload carries the originating alert_id, allowing the app to attach the report to the matching alert in its history[cite: 1].
- REST Fallback: A new GET /reports/{alert_id} endpoint exposes the persisted report for clients that reconnect after the alert (e.g., after a WebSocket drop)[cite: 1].

- Inline Presentation: The mobile app renders COMPLETED reports as a highlighted banner for the latest alert and as a dedicated card inside the alert history feed, showing the generated summary and per-item recommendations[cite: 1].

### 8.5. Operational Notes

- Compose Profile: The ollama and ai-worker services are gated behind the ai profile so that the default docker compose up remains lightweight and CI stays hermetic[cite: 1]. Enable the pipeline
with docker compose --profile ai up -d[cite: 1].
- Feature Flag: The main worker only enqueues reports when AI_REPORT_ENABLED=true (default false) to avoid orphaned PENDING rows when the AI profile is not running[cite: 1].
- Timeouts: Inference requests honor OLLAMA_TIMEOUT; the Ollama service uses KEEP_ALIVE to reduce cold-start latency between alerts[cite: 1].

## 9. DevOps Automation & Scripting (v2.0.0)

With the release of v2.0.0, QuakeGuard introduces a “Zero-Config” orchestration pipeline designed to eliminate manual setup overhead and credential mismanagement across the distributed architecture. The scripts/ directory provides a suite of bash tools that handle everything from dynamic cryptographic generation to multi-terminal provisioning.

### 9.1. The QuakeGuard Orchestrator (quakeguard_init.sh)

The quakeguard_init.sh script serves as the master entrypoint for the local development and testing environment. When executed on a fresh clone of the repository, it automates the entire lifecycle:

1. Environment Provisioning: It detects if the core .env configurations are missing and automatically invokes generate_secrets.sh (see below) to populate them securely.
2. Dynamic Tunnel Negotiation: It invokes tunnel_init.sh to negotiate an ephemeral Cloudflare HTTPS tunnel, instantly injecting the resulting https://*.trycloudflare.com URL into both the ESP32 firmware C++ build configuration and the React Native mobile client.
3. Multi-Process Boot: Utilizing ptyxis (or tmux), it spawns three isolated, parallel terminal sessions:
- Backend: Rebuilds and launches the Docker Compose stack (including the AI-Worker profile).
- Mobile: Clears the Expo cache and starts the React Native bundler.
- IoT Edge: Triggers a PlatformIO run -t upload -t monitor command to compile the firmware with the injected dynamic URLs and flash the attached ESP32-C3 node.

### 9.2. Idempotent Secrets Sync (generate_secrets.sh)

To enforce the “Zero-Trust” architecture without manual pain, generate_secrets.sh generates and
synchronizes cryptographic tokens (ENROLLMENT_TOKEN, IOT_API_KEY, MOBILE_WS_TOKEN).
- Smart Generation: It uses openssl rand -hex 32 to generate secure 256-bit keys, substituting them into the respective .env files via regex.
- Conflict Resolution: If keys are modified manually and become desynchronized across the backend, mobile, or firmware, the script performs a Global Mismatch Check. It prompts the developer via an interactive [b/m/f] prompt to select the “Source of Truth,” subsequently synchronizing the remaining systems to match the selected component.
- Dependency Checks: The script actively scans for missing manual configuration (such as the HiveMQ MQTT broker credentials) and forces a loud terminal warning to ensure the data plane is fully established before boot.

### 9.3. E2E Pipeline Stress Testing

The automation suite also includes Python-based stress testers to validate the deployment’s resilience:
- load_test.py: Simulates the “Thundering Herd” effect by spawning 150 concurrent asynchronous sensors, blasting the API to validate the Redis sliding-window rate limiter and the FastAPI concurrency limits. A successful run finishes with a 🏆 SYSTEM CERTIFIED banner.
- simulate_zone.py: Streams synthetic, scaled acceleration telemetry into specific PostGIS zones to visualize live graphs on the React Native mobile app without triggering a full E2E pipeline crash.

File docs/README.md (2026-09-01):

# QuakeGuard — Documentation Hub

Single source of truth for QuakeGuard documentation. Each subfolder has a single
purpose:

```
docs/
├── whitepaper/          # main.typ + 01-architecture..08-ai.typ + assets/ + PDF
├── web/                 # quakeguard.html/css/js/demo.js + assets/ (see README)
├── README.md            # this hub guide
├── extract.sh           # LLM context export (stays at docs/ root)
└── codebase_docs.txt    # generated by extract.sh (stays at docs/ root)
```

## Contents

| Directory | Covers |
|---|---|
| [`whitepaper/`](whitepaper/README.md) | Typst sources for the technical report, compiled into `QuakeGuard_Technical_Report_v2.0.0.pdf` |
| [`web/`](web/) | QuakeGuard page artifacts (html/css/js/demo + assets) synced to the `GiZano.github.io` Pages site via CI |

## Compiling the whitepaper PDF

Requires [Typst](https://typst.app/) (`typst` on PATH) and the Liberation Serif font family.

```bash
cd docs
typst compile whitepaper/main.typ whitepaper/QuakeGuard_Technical_Report_v2.0.0.pdf
```

The output PDF is a local build artifact and is intentionally **not** tracked in git.

## Editing the web page

Edit only inside `docs/web/`. A CI workflow (`deploy-gh-pages.yml`) syncs changes
into the `GiZano/GiZano.github.io` Pages repo; never edit the site repo directly.

## `extract.sh`

`extract.sh` compiles the entire QuakeGuard codebase into a single `codebase_docs.txt` file for LLM context. Run it from this directory when you need a fresh export:

```bash
cd docs
./extract.sh
```

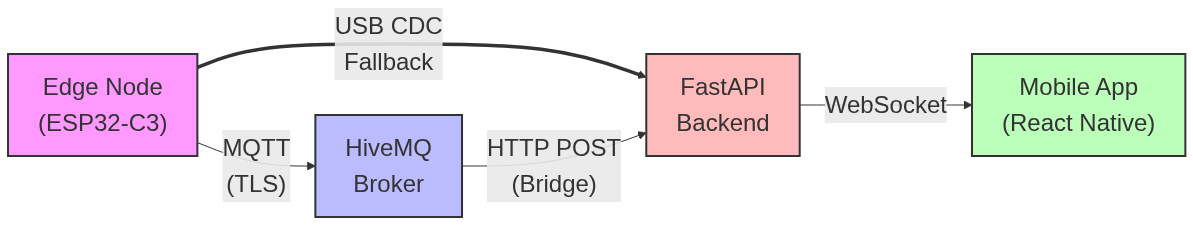
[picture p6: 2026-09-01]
docs/whitepaper/assets/01-architecture.png

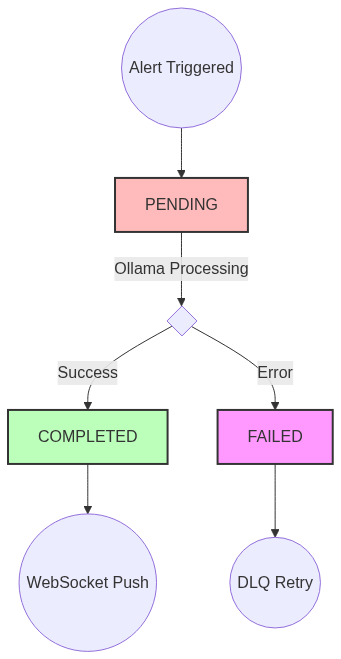
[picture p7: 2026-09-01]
docs/whitepaper/assets/08-ai.png

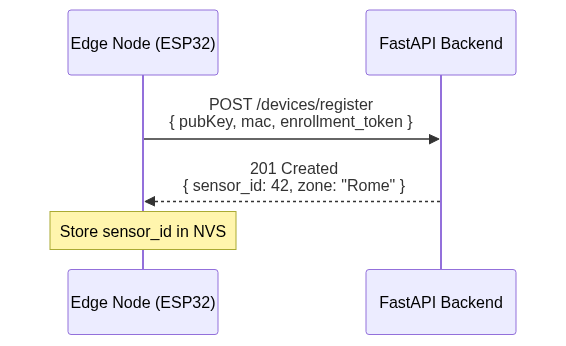
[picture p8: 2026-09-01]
docs/whitepaper/assets/03-security.png

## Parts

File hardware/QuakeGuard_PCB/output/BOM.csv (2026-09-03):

Refs | Value | Footprint | Qty | DNP
C1 | 10µF | Capacitor_THT:CP_Radial_D5.0mm_P2.50mm | 1
C2 | 0.1µF | Capacitor_THT:C_Disc_D5.0mm_W2.5mm_P5.00mm | 1
C3 | 10µF | Capacitor_THT:CP_Radial_D5.0mm_P2.50mm | 1
D1 | Green | LED_THT:LED_D5.0mm | 1
D2 | Blue | LED_THT:LED_D5.0mm | 1
D3 | Red | LED_THT:LED_D5.0mm | 1
J1 | ESP32-C3[L] | Connector_PinSocket_2.54mm:PinSocket_1x08_P2.54mm_Vertical | 1
J2 | ESP32-C3[R] | Connector_PinSocket_2.54mm:PinSocket_1x08_P2.54mm_Vertical | 1
J3 | ADXL345 | Connector_PinSocket_2.54mm:PinSocket_1x08_P2.54mm_Vertical | 1
J4 | NEO-6M | Connector_PinSocket_2.54mm:PinSocket_1x05_P2.54mm_Vertical | 1
R1 | 330Ω | Resistor_THT:R_Axial_DIN0207_L6.3mm_D2.5mm_P10.16mm_Horizontal | 1
R2 | 330Ω | Resistor_THT:R_Axial_DIN0207_L6.3mm_D2.5mm_P10.16mm_Horizontal | 1
R3 | 330Ω | Resistor_THT:R_Axial_DIN0207_L6.3mm_D2.5mm_P10.16mm_Horizontal | 1

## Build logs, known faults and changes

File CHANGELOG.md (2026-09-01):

# Changelog

All notable changes to this project will be documented in this file.

The format is based on [Keep a Changelog](https://keepachangelog.com/en/1.0.0/),
and this project adheres to [Semantic Versioning](https://semver.org/spec/v2.0.0.html).

## [2.0.1] - 2026-09-01
### Changed
- **Documentation Polish (Zenodo Sync):** Removed residual LLM tags (`[cite: 1]`) from the technical whitepaper.
- **Architectural Coherence:** Aligned documentation across PDF, GitHub Wiki, and project website regarding tunnel architecture (Cloudflare) and threshold/anti-replay values (300s).
- **Project Licensing Health:** Clearly detailed testing pipelines, AGPL-3.0 software licensing, and CERN-OHL hardware licensing in the whitepaper and wiki.
- **Hardware Documentation:** Clarified `1.8f` firmware threshold vs `2.4` SIL offline threshold; contextualized ROC curve as preliminary MVP validation.
- **Roadmap & Threat Model:** Added detailed v1.2.x changelog to the whitepaper and clarified `ATECC608A` secure element alignment to Roadmap Phase R3.

## [2.0.0] - 2026-09-01
### Added
- **Hybrid Networking Architecture:** Transitioned from pure cloud to a Local-First / Cloud-Hybrid architecture for robust exhibition reliability.
- **Local Factory Provisioning:** Provisioning now uses local HTTP to bypass ESP32 mbedTLS memory limitations with large Let's Encrypt tunnel certificates.
- **DevOps Orchestration:** Introduced `scripts/quakeguard_init.sh` (Ptyxis 3-window orchestrator) and `scripts/tunnel_init.sh` (automated Cloudflare quick-tunnel generation with dynamic `.env` injection and automatic firmware rebuild).
- **Synchronized GNSS & Timing:** Implemented `NTP + PPS` (GPIO 2) discipline for millisecond-accurate time synchronization, replacing the hardcoded fix.
- **ADXL345 Hardware Calibration:** Introduced boot-time routine computing static offsets from 100 samples and writing biases directly to hardware registers (`OFSX`, `OFSY`, `OFSZ`).
- **SIL Validation (INGV FDSN):** Integrated ObsPy and FDSN queries to INGV for algorithmic validation on public, reproducible open data. ROC curve documented, completing the R1 validation milestone.
- **Hardware Documentation:** Documented diagnostic LED patterns (including Serial Fallback) and integrated Proprietary Hardware (v2.0.0 PCB) assembly visuals into the whitepaper and website.

### Changed
- Shifted default fallback GNSS coordinates (simulated and IoT) to Milan (Italy North) for regional alignment.
- Refactored `firmware/esp32_config.env.example` as the standard configuration template, reflecting the new Local IP architecture.
- Version artifacts bumped to v2.0.0 across documentation and web assets.

### Fixed
- **UnboundLocalError in Backend Worker:** Fixed a bug where a sub-threshold seismic event (`magnitude < 4.5`) would trigger an `UnboundLocalError` on `triangulation_data`, leading to batch rollback and empty dashboard graphs.
- **Subnet DNS Patch:** Removed erroneous `WiFi.config` in firmware that forced `INADDR_NONE` on the subnet mask, causing local routing failures (errno 118).
- **Mobile Map Crash:** Resolved a critical React Native `AIRMapMarker` rendering crash by implementing a strict null/undefined coordinate filter in the sensor mapping array.
- **Mobile UI Polish:** Updated the `MAG` badge to default to `0.00` (instead of `N/A`) and implemented dynamic Y-axis domain scaling (0 to 5+) for the `VictoryChart` seismograph.

## [1.2.2] - 2026-08-31
### Added
- **Zero-Trust USB Serial Fallback:** ECDSA-signed telemetry over USB CDC (`[QG:FB]` frames) when MQTT/WiFi is unreachable. Pure C++ core shared by firmware (`networkTask`) and host SIL validation (`test_serial_fallback.cpp`).
- **Host Serial Bridge:** `firmware/tools/serial_bridge.py` reads CDC frames and forwards to ingestion API with SSRF-safe URL validation.

### Changed
- **SonarCloud Quality Gate Fixes:** Removed `'unsafe-inline'` from CSP (externalized gtag to `analytics.js`), fixed dropdown accessibility (`<button>` instead of `<a role="button">`), replaced `role="status"` with native `<output>` element.
- **Code Quality Improvements:** Reduced cognitive complexity in backend (`geo.py`, `worker.py`, `timescale.py`), eliminated duplicate "Zone not found" literal, flattened nested conditionals in simulator and mobile, modernized firmware C++ (removed char arrays, fixed enum usage).
- **Version artifacts bumped to v1.2.2** (CITATION.cff, mobile footer, README roadmap, site labels).

### Fixed
- Serial bridge exit code returns non-zero on serial port open failure (S3516 blocker fix).

## [1.2.1] - 2026-08-14
### Added
- **Geo-Zoning:** PostGIS zones as the source of truth (`Zone` model, `GET /zones`, `POST /zones/`), with a geohash-based Redis fast path for coordinate→zone lookup.
- **Zone Detection:** `GET /zones/locate` resolves a device's GPS position into a monitored polygon; Settings now ships "Detect my zone via GPS".
- **Per-Zone Seismograph:** `GET /zones/{zone_id}/readings` + `DELETE /zones/{zone_id}/readings`; the mobile dashboard renders a live seismograph per zone (horizontal zone strip) instead of mixing network-wide telemetry.
- **Per-Area Cooldown Fragmentation:** alert cooldown keys are now area-based (geohash region or zone), not global.
- **GNSS-Ready Data Model:** `Sensor.last_fix_at`, `Reading.lat/lon` captured at ingestion for area-fragmented cooldowns and future spatial correlation.
- **Per-Zone Alerts Feed:** `GET /zones/{zone_id}/alerts` retrieves the confirmed seismic alerts raised for a single area.
- **Live Chart Overhaul (mobile):** sliding window anchored to the wall clock (stale readings leave the window), linear MAG scale (MIN 3.5 / MED 4.0 / ALTO 4.5) with the axis pinned left, positive X seconds and a centered `TIME` label; the trace always renders inside the plot.
- **Settings Explore Section:** links to the GitHub repository (`GiZano/QuakeGuard`) and the QuakeGuard site; `QuakeGuard v1.2.1` footer.

### Changed
- Worker alert pipeline uses per-area cooldown keys and rounds-trip normalization (magnitude estimation shared with the mobile client).
- Peripheral MQTT subscriber wiring and `scripts/simulate_zone.py` updated for the per-zone stream flow.
- Version artifacts bumped to v1.2.1 (CITATION.cff, mobile footer, README roadmap).

## [1.2.0] - 2026-08-06
### Added
- **On-Premise AI Emergency Reports:** New AI layer generates human-readable emergency reports from confirmed seismic alerts via a local Ollama LLM (`llama3.2:1b` default), keeping telemetry on the host.
- **`ollama_client.py`:** Deterministic report generation (`temperature 0.0`, `top_k 1`, streaming disabled) with a strict system prompt ("Only use the provided JSON telemetry. Do not invent data.") and explicit `"AI report unavailable."` fallback on failure.
- **`EmergencyReport` Model & State Machine:** `PENDING → COMPLETED | FAILED` lifecycle, persisted in PostgreSQL alongside alerts.
- **`ai_report_worker.py`:** Dedicated consumer of the `ai_report_queue`; publishes `EMERGENCY_REPORT` to the `ai_reports` Redis channel, routes failures to `ai_report_queue_dlq`, and handles graceful shutdown.
- **Worker Integration:** Alert engine now enqueues report jobs non-blocking (gated by `AI_REPORT_ENABLED`, default `false`); alert payloads carry `alert_id`.
- **`GET /reports/{alert_id}`:** REST endpoint for report retrieval after WebSocket reconnect.
- **Docker Compose `ai` profile:** `ollama` and `ai-worker` services behind a profile; `init-scripts/ollama-entrypoint.sh` auto-pulls the model on startup.
- **Mobile Report UI:** Inline AI report banner + history cards (summary + recommendations; "Report unavailable" badge on `FAILED`), driven by the `ai_reports` WebSocket channel.
- **Unit Tests:** Coverage for the Ollama client, AI worker state machine, worker enqueue path, and EmergencyReport model (68 backend tests; mobile store tests for report handling).

### Changed
- WebSocket broadcaster subscribes to the `ai_reports` channel in addition to `quake_alerts`.
- Mobile `WebSocketContext` handles `EMERGENCY_REPORT` messages and stores the latest report; `useAlertStore` keeps a `reports` map keyed by `alert_id`.

## [1.1.0] - 2026-07-29
### Added
- **HiveMQ Cloud MQTT Integration:** Migrated from local MQTT broker to a fully managed, TLS-secured cloud broker.
- **Python MQTT Bridge (`mqtt_subscriber.py`):** New service to proxy MQTT payloads to the HTTP ingestion pipeline securely.
- **ngrok HTTPS Tunnel:** Enabled secure, remote exposure of the control plane for device registration.
- **Docs as Code:** Added modular Typst documentation (`docs/`) outlining the entire system architecture.

### Changed
- Refactored ESP32 firmware to connect to port 8883 (TLS) and authenticate via standard MQTT credentials.
- Updated Mobile React Native App to point to the new remote WebSocket endpoint.
- Hardened Redis `seismic_events` queue to handle edge-case worker disconnects.

## [1.0.0] - 2026-06-15
### Added
- Initial stable release for the Hackersgen contest.
- STA/LTA seismic detection algorithm implemented in C++ (ESP32-C3).
- FastAPI backend with PostgreSQL + PostGIS integration for sensor mapping.
- ECDSA cryptographic signing and Zero-Trust device provisioning.
- React Native Mobile App with WebSockets and native haptic alerts.
- End-to-End stress test suite (`tests/stress_test.py`).

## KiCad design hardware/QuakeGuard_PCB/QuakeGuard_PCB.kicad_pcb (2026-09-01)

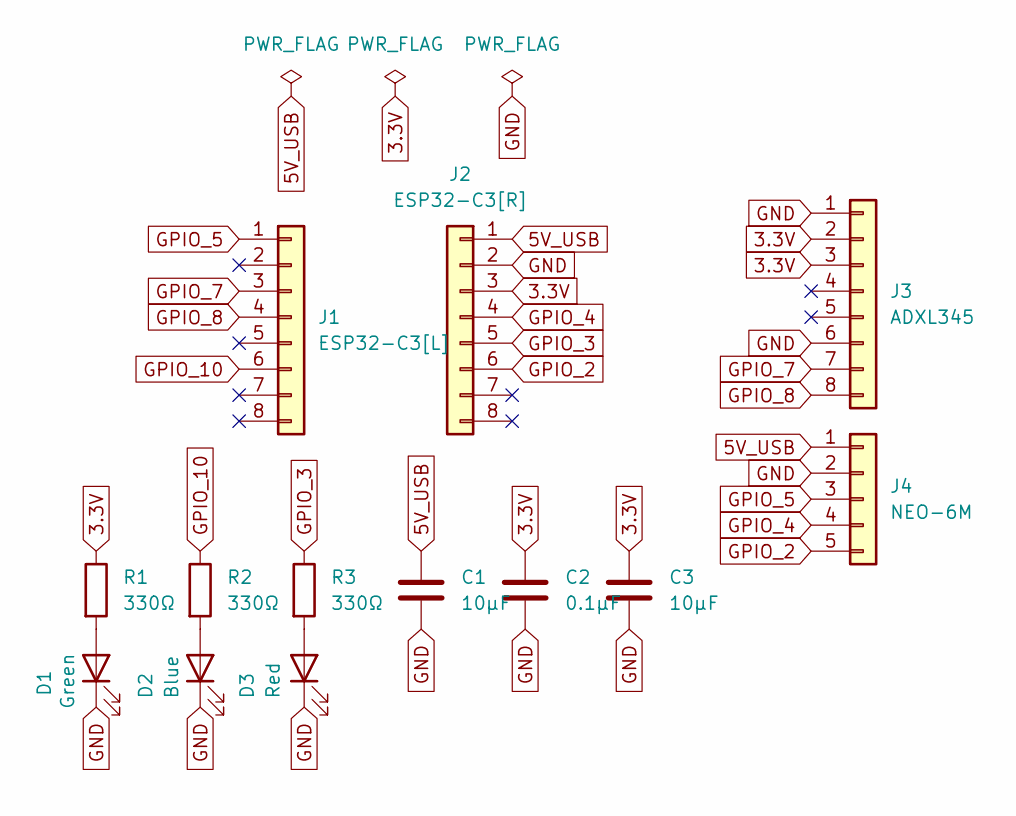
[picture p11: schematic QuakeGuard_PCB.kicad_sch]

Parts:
C1, C3: 10µF; CP_Radial_D5.0mm_P2.50mm
C2: 0.1µF; C_Disc_D5.0mm_W2.5mm_P5.00mm
D1: Green; LED_D5.0mm
D2: Blue; LED_D5.0mm
D3: Red; LED_D5.0mm
J1: ESP32-C3[L]; PinSocket_1x08_P2.54mm_Vertical
J2: ESP32-C3[R]; PinSocket_1x08_P2.54mm_Vertical
J3: ADXL345; PinSocket_1x08_P2.54mm_Vertical
J4: NEO-6M; PinSocket_1x05_P2.54mm_Vertical
R1, R2, R3: 330Ω; R_Axial_DIN0207_L6.3mm_D2.5mm_P10.16mm_Horizontal

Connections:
3.3V: C2.1, C3.1, J2.3, J3.2, J3.3, R1.1
5V_USB: C1.1, J2.1, J4.1
GND: C1.2, C2.2, C3.2, D1.1 (K), D2.1 (K), D3.1 (K), J2.2, J3.1, J3.6, J4.2
GPIO_2: J2.6, J4.5
GPIO_3: J2.5, R3.1
GPIO_4: J2.4, J4.4
GPIO_5: J1.1, J4.3
GPIO_7: J1.3, J3.7
GPIO_8: J1.4, J3.8
GPIO_10: J1.6, R2.1
unnamed: D1.2 (A), R1.2
unnamed: D2.2 (A), R2.2
unnamed: D3.2 (A), R3.2

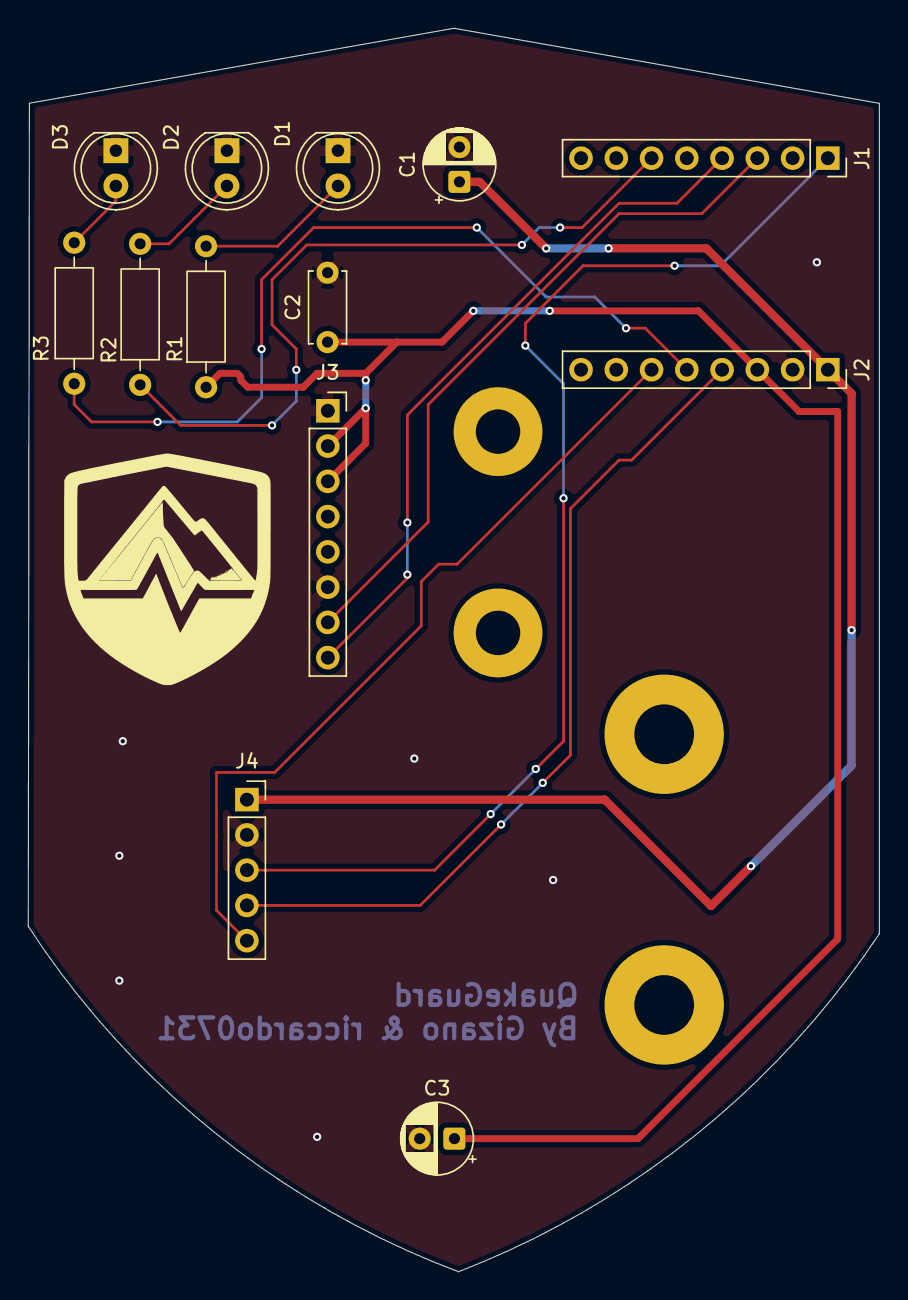
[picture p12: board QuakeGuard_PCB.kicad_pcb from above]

Board: 2 copper layers, 61.3 x 89.6 mm, 13 parts (0 on the bottom side), 13 nets.

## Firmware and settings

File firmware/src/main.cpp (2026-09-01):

/**
 * Project: QuakeGuard - Professional Seismic Node
 * Version: 1.3.0-GNSS-PPS
 * Target Hardware: ESP32-C3 SuperMini + ADXL345 + NEO-6M (JLCPCB)
 * Author: GiZano
 *
 * CHANGELOG:
 * - v2.0.0: GNSS on UART1 RX 5 / TX 4 (JLCPCB J4), PPS on GPIO 2, fallback
 * coords via .env, LED blue (10) PWM dimmed + red (3) 3s quake pulse + boot
 * self-test, NTP+PPS discipline prep.
 */

#include <Adafruit_ADXL345_U.h>
#include <Adafruit_Sensor.h>
#include <Arduino.h>
#include <ArduinoJson.h>
#include <HTTPClient.h>
#include <Preferences.h>
#include <PubSubClient.h>
#include <WiFi.h>
#include <WiFiManager.h>
#include <Wire.h>
#include <time.h>

// --- Cryptographic Libraries (MbedTLS) ---
#include "Calibration.h"
#include "DetectionCore.h"
#include "GnssModule.h"
#include "SerialFallback.h"
#include "mbedtls/ctr_drbg.h"
#include "mbedtls/ecdsa.h"
#include "mbedtls/entropy.h"
#include "mbedtls/error.h"
#include "mbedtls/pk.h"
#include <array>
#include <chrono>
#include <vector>

// --------------------------------------------------------------------------
// HARDWARE & SERVER CONFIGURATION
// --------------------------------------------------------------------------
constexpr int I2C_SDA_PIN = 7;
constexpr int I2C_SCL_PIN = 8;
constexpr int I2C_CLOCK_SPEED = 100000;

constexpr int LED_BLUE_PIN =
    10; // connection state: double->wifi, single->server, solid->connected
constexpr int LED_RED_PIN = 3; // quake detected: on 3 s

#ifndef SERVER_HOST
#define SERVER_HOST "your-tunnel-id.trycloudflare.com"
#endif
#ifndef SERVER_PORT
#define SERVER_PORT 80
#endif
#ifndef SERVER_PROTOCOL
#define SERVER_PROTOCOL "https"
#endif
#ifndef SERVER_PATH
#define SERVER_PATH "/readings/"
#endif
#ifndef SERVER_REGISTER_PATH
#define SERVER_REGISTER_PATH "/devices/register"
#endif
#ifndef MQTT_BROKER_HOST
#error "MQTT_BROKER_HOST is missing! Add it to esp32_config.env"
#endif
#ifndef MQTT_BROKER_PORT
#define MQTT_BROKER_PORT 8883
#endif
#ifndef MQTT_USERNAME
#error "MQTT_USERNAME is missing! Add it to esp32_config.env"
#endif
#ifndef MQTT_PASSWORD
#error "MQTT_PASSWORD is missing! Add it to esp32_config.env"
#endif

#ifndef SERIAL_FALLBACK_ENABLED
#define SERIAL_FALLBACK_ENABLED 1
#endif
#ifndef SERIAL_FALLBACK_MARKER
#define SERIAL_FALLBACK_MARKER "[QG:FB]"
#endif

#ifndef ENROLLMENT_TOKEN
#ifndef __INTELLISENSE__
                               // 1. If the REAL compiler doesn't see the token,
                               // crash the build to protect us!
#error                                                                         \
    "CRITICAL BUILD ERROR: ENROLLMENT_TOKEN is missing! Add it to esp32_config.env"
#else
                               // 2. If VSCode's UI is looking at the file, give
                               // it a fake token so it stops crying on line
                               // 168!
#define ENROLLMENT_TOKEN "vscode_dummy_token"
#endif
#endif

// Global Dynamic Sensor ID
static int globalSensorID = 0;
Adafruit_ADXL345_Unified accel = Adafruit_ADXL345_Unified(12345);

// LED state (v2.0.0) — blue dimmed via PWM, red 3 s pulse
static volatile unsigned long g_redLedOffAt = 0; // NOSONAR
static constexpr int BLUE_BRIGHT =
    100; // 0-255, ~40% to slightly dim the blue LED (was 255)

inline void triggerQuakeLed() {
  digitalWrite(LED_RED_PIN, HIGH);
  Serial.println("[LED] Red ON (quake) for 3 s");
  g_redLedOffAt = millis() + 3000;
}

inline void updateConnectionLed(bool wifiConnected, bool serverConnected) {
  // Red LED auto-off
  if (g_redLedOffAt != 0 && (long)(millis() - g_redLedOffAt) >= 0) {
    digitalWrite(LED_RED_PIN, LOW);
    g_redLedOffAt = 0;
    Serial.println("[LED] Red OFF");
  }
  // Blue LED: PWM dimmed (analogWrite) — double blink WiFi, single blink
  // server, solid connected
  if (!wifiConnected) {
    unsigned long phase = millis() % 1000;
    bool on = (phase < 100) || (phase >= 200 && phase < 300);
    analogWrite(LED_BLUE_PIN, on ? BLUE_BRIGHT : 0);
  } else if (!serverConnected) {
    unsigned long phase = millis() % 1000;
    bool on = (phase < 200);
    analogWrite(LED_BLUE_PIN, on ? BLUE_BRIGHT : 0);
  } else {
    analogWrite(LED_BLUE_PIN, BLUE_BRIGHT);
  }
}

// Boot self-test: blink both LEDs to verify wiring (red active-HIGH:
// GPIO3->R3->D3->GND)
inline void ledBootTest() {
  Serial.println("[LED] Boot test: blue + red");
  for (int i = 0; i < 2; i++) {
    digitalWrite(LED_BLUE_PIN, HIGH); // full bright for test
    digitalWrite(LED_RED_PIN, HIGH);
    delay(250);
    digitalWrite(LED_BLUE_PIN, LOW);
    digitalWrite(LED_RED_PIN, LOW);
    delay(250);
  }
  // leave both off, updateConnectionLed will drive blue from now on
  analogWrite(LED_BLUE_PIN, 0);
}

// --------------------------------------------------------------------------
// RTOS & DSP DEFINITIONS
// --------------------------------------------------------------------------
QueueHandle_t eventQueue;

struct SeismicEvent {
  float magnitude;
  unsigned long event_millis;
};

constexpr float TRIGGER_RATIO = 1.8f;
constexpr float NOISE_FLOOR = 0.04f;
constexpr float HPF_ALPHA = 0.9f;

// Bounded in-memory retention for events with no delivery path.
constexpr size_t RETENTION_CAPACITY = 100;

// --------------------------------------------------------------------------
// CRYPTO SUBSYSTEM
// --------------------------------------------------------------------------
static Preferences preferences;

class CryptoContext {
  mbedtls_entropy_context entropy_;
  mbedtls_ctr_drbg_context ctr_drbg_;
  mbedtls_pk_context pk_context_;

public:
  void init();
  String getPublicKeyHex();
  String signMessage(const String &message);
};

CryptoContext &crypto() {
  static CryptoContext c;
  return c;
}

void CryptoContext::init() {
  mbedtls_entropy_init(&entropy_);
  mbedtls_ctr_drbg_init(&ctr_drbg_);
  mbedtls_pk_init(&pk_context_);

  constexpr const char pers[] = "quake_guard_signer";
  mbedtls_ctr_drbg_seed(&ctr_drbg_, mbedtls_entropy_func, &entropy_,
                        (const unsigned char *)pers, sizeof(pers) - 1);

  preferences.begin("quake-keys", false);

  if (!preferences.isKey("priv_key")) {
    Serial.println("[SEC] Generating New ECDSA Key Pair...");
    mbedtls_pk_setup(&pk_context_, mbedtls_pk_info_from_type(MBEDTLS_PK_ECKEY));
    mbedtls_ecp_gen_key(MBEDTLS_ECP_DP_SECP256R1, mbedtls_pk_ec(pk_context_),
                        mbedtls_ctr_drbg_random, &ctr_drbg_);
    std::array<unsigned char, 128> priv_buf;
    int ret = mbedtls_pk_write_key_der(&pk_context_, priv_buf.data(),
                                       priv_buf.size());
    preferences.putBytes("priv_key", priv_buf.data() + priv_buf.size() - ret,
                         ret);
    Serial.println("[SEC] Keys Generated.");
  } else {
    Serial.println("[SEC] Loading Existing Keys...");
    size_t len = preferences.getBytesLength("priv_key");
    std::vector<uint8_t> buf(len);
    preferences.getBytes("priv_key", buf.data(), len);
    mbedtls_pk_parse_key(&pk_context_, buf.data(), len, NULL, 0);
  }
}

String CryptoContext::getPublicKeyHex() {
  std::array<unsigned char, 128> pub_buf;
  int ret =
      mbedtls_pk_write_pubkey_der(&pk_context_, pub_buf.data(), pub_buf.size());
  int len = ret;
  int start_index = pub_buf.size() - len;

  String hexKey = "";
  for (int i = start_index; i < static_cast<int>(pub_buf.size()); i++) {
    std::array<char, 3> buf;
    snprintf(buf.data(), buf.size(), "%02x", pub_buf[i]); // NOSONAR(cpp:S6494) - std::format unavailable on ESP32
    hexKey += buf.data();
  }
  return hexKey;
}

String CryptoContext::signMessage(const String &message) {
  std::array<unsigned char, 32> hash;
  std::array<unsigned char, MBEDTLS_ECDSA_MAX_LEN> sig;
  size_t sig_len = 0;
  mbedtls_md_context_t ctx;
  mbedtls_md_init(&ctx);
  mbedtls_md_setup(&ctx, mbedtls_md_info_from_type(MBEDTLS_MD_SHA256), 0);
  mbedtls_md_starts(&ctx);
  mbedtls_md_update(&ctx, (const unsigned char *)message.c_str(),
                    message.length());
  mbedtls_md_finish(&ctx, hash.data());
  mbedtls_md_free(&ctx);
  mbedtls_pk_sign(&pk_context_, MBEDTLS_MD_SHA256, hash.data(), 0, sig.data(),
                  &sig_len, mbedtls_ctr_drbg_random, &ctr_drbg_);

  String hexSig = "";
  for (size_t i = 0; i < sig_len; i++) {
    std::array<char, 3> buf;
    snprintf(buf.data(), buf.size(), "%02x", sig[i]); // NOSONAR(cpp:S6494)
    hexSig += buf.data();
  }
  return hexSig;
}

// --------------------------------------------------------------------------
// PROVISIONING LOGIC
// --------------------------------------------------------------------------
bool performProvisioning() {
  Serial.println("\n[PROV] Starting Device Handshake...");
  if (WiFi.status() != WL_CONNECTED) {
    Serial.println("[PROV] Error: No WiFi connection.");
    return false;
  }

  HTTPClient http;
  WiFiClientSecure secureClient;
  secureClient.setInsecure(); // Bypass Root CA validation for Let's Encrypt
                              // (Tailscale/Cloudflare)

  // SERVER_HOST may be configured with or without a leading scheme; normalize
  // it so a "https://host" value cannot produce "https://https://host". The
  // actual request protocol comes from SERVER_PROTOCOL below.
  auto host = String(SERVER_HOST);
  auto scheme = host.indexOf("://");
  if (scheme != -1) {
    host.remove(0, scheme + 3);
  }

  String url = String(SERVER_PROTOCOL) + "://" + host;
  int serverPort = SERVER_PORT;
  if (serverPort != 80 && serverPort != 443) {
    url += ":" + String(serverPort);
  }
  url += SERVER_REGISTER_PATH;

  Serial.printf("[PROV] Connecting to: %s\n", url.c_str());

  if (url.startsWith("https")) {
    http.begin(secureClient, url);
  } else {
    http.begin(url);
  }
  http.addHeader("Content-Type", "application/json");
  http.addHeader("ngrok-skip-browser-warning", "true");
  http.setTimeout(15000);

  JsonDocument doc;
  doc["public_key_hex"] = crypto().getPublicKeyHex();
  doc["mac_address"] = WiFi.macAddress();
  doc["enrollment_token"] = ENROLLMENT_TOKEN;

#ifdef GNSS_ENABLED
  // GNSS-ready: report the real fix when available, else the last-known fix
  // persisted in NVS. If neither exists, use fallback coords from .env
  // (indoor testing) or omit -> backend assigns "Unknown Region".
  GnssFix fix;
  if (gnss().getFix(fix)) {
    doc["latitude"] = fix.latitude;
    doc["longitude"] = fix.longitude;
    Serial.printf("[PROV] Sending fix: %.5f, %.5f (from %s)\n", fix.latitude,
                  fix.longitude, fix.from_storage ? "NVS" : "GNSS");
  } else {
#ifdef GNSS_FALLBACK_LAT
    doc["latitude"] = GNSS_FALLBACK_LAT;
    doc["longitude"] = GNSS_FALLBACK_LON;
    Serial.printf(
        "[PROV] Using fallback coords: %.5f, %.5f (GNSS no-fix, indoor)\n",
        (double)GNSS_FALLBACK_LAT, (double)GNSS_FALLBACK_LON);
#else
    Serial.println("[PROV] No GNSS fix available: omitting coordinates");
#endif
  }
#else
#ifdef GNSS_FALLBACK_LAT
  doc["latitude"] = GNSS_FALLBACK_LAT;
  doc["longitude"] = GNSS_FALLBACK_LON;
  Serial.printf("[PROV] GNSS disabled, using ENV fallback coords: %.5f, %.5f\n",
                (double)GNSS_FALLBACK_LAT, (double)GNSS_FALLBACK_LON);
#else
  Serial.println("[PROV] GNSS disabled: omitting coordinates (backend assigns "
                 "Unknown Region)");
#endif
#endif

  String requestBody;
  serializeJson(doc, requestBody);

  int httpResponseCode = http.POST(requestBody);

  if (httpResponseCode == 200 || httpResponseCode == 201) {
    String response = http.getString();
    JsonDocument resDoc;
    deserializeJson(resDoc, response);

    int newID = resDoc["sensor_id"];
    if (newID > 0) {
      preferences.begin("quake-config", false);
      preferences.putInt("sensor_id", newID);
      preferences.end();
      globalSensorID = newID;
      Serial.printf("[PROV] SUCCESS! Assigned Sensor ID: %d\n", globalSensorID);
      Serial.printf("[PROV] Public key: %s\n",
                    crypto().getPublicKeyHex().c_str());
      http.end();
      return true;
    }
  } else {
    Serial.printf("[PROV] Registration Failed. HTTP Code: %d\n",
                  httpResponseCode);
  }
  http.end();
  return false;
}

// --------------------------------------------------------------------------
// TASK 1: SENSOR ACQUISITION
// --------------------------------------------------------------------------
void sensorTask(void *pvParameters) { // NOSONAR
  sensors_event_t event;

  // Pure-C++ STA/LTA core, shared with the host SIL validation (same source).
  SeismicDetector detector(HPF_ALPHA, TRIGGER_RATIO, NOISE_FLOOR);

  Serial.println("[SENSOR] Task Active. Stabilizing and filling buffers...");

  TickType_t xLastWakeTime = xTaskGetTickCount();
  const TickType_t xFrequency = pdMS_TO_TICKS(10); // Exactly 100Hz

  for (;;) {
    vTaskDelayUntil(&xLastWakeTime, xFrequency);
    accel.getEvent(&event);
    float raw_mag = SeismicDetector::norm3(
        event.acceleration.x, event.acceleration.y, event.acceleration.z);

    // Clock-injected: the detector receives the same millis() the firmware
    // would use.
    if (detector.push(raw_mag, millis())) {
      Serial.printf("[SENSOR] EARTHQUAKE! Ratio: %.2f (Mag: %.3f G)\n",
                    detector.lastRatio(), detector.lastSTA());
      // The backend expects the physical PGA (m/s^2 or Gs) for the magnitude calculation, not the STA/LTA trigger ratio!
      SeismicEvent evt = {detector.lastSTA(), millis()};
      xQueueSend(eventQueue, &evt, 0);
    }
  }
}

// --------------------------------------------------------------------------
// TASK 2: NETWORK DISPATCH (MQTT + USB SERIAL FALLBACK)
// --------------------------------------------------------------------------
static void deliverEvent(PubSubClient &mqttClient, DeliveryPath path, int val,
                         time_t evt_time, const String &sig);

#if SERIAL_FALLBACK_ENABLED
static void drainRetention(RetentionRing<RETENTION_CAPACITY> &retention,
                           PubSubClient &mqttClient, bool mqttUp, bool usbHost,
                           bool timeValid, time_t epochAtSync,
                           unsigned long millisAtSync) {
  if (retention.empty() || !timeValid)
    return;
  DeliveryPath path =
      decidePath(mqttUp && timeValid, usbHost,
                 timeValid); // NOSONAR(cpp:S5811) - using enum requires C++20
  if (path != DeliveryPath::MQTT && path != DeliveryPath::SERIAL_CDC)
    return;
  SerialEvent retainedEvt;
  while (retention.pop(retainedEvt)) {
    time_t report_time = epochAtSync + (millis() - millisAtSync) / 1000;
    String payload = String(retainedEvt.value) + ":" + String(report_time);
    String sig = crypto().signMessage(payload);
    deliverEvent(mqttClient, path, retainedEvt.value, report_time, sig);
    triggerQuakeLed();
  }
}
#endif

static void deliverEvent(PubSubClient &mqttClient, DeliveryPath path, int val,
                         time_t evt_time, const String &sig) {
  if (path == DeliveryPath::MQTT) { // NOSONAR(cpp:S5811)
    JsonDocument doc;
    doc["value"] = val;
    doc["sensor_id"] = globalSensorID;
    doc["device_timestamp"] = evt_time;
    doc["signature_hex"] = sig;

    String json;
    serializeJson(doc, json);

    // FIRE AND FORGET! Milliseconds instead of HTTP round-trips!
    if (mqttClient.publish("quakeguard/telemetry", json.c_str())) {
      Serial.println("[NET] MQTT Publish OK.");
    } else {
      Serial.println("[NET] MQTT Publish FAILED.");
    }
  } else {
    // USB serial fallback: machine-readable frame on the CDC port.
    Serial.print(buildSerialFrame(SERIAL_FALLBACK_MARKER, val, globalSensorID,
                                  (long)evt_time, sig.c_str())
                     .c_str());
    Serial.println();
    Serial.println("[NET] Serial Fallback Publish OK.");
  }
}

void networkTask(void *pvParameters) { // NOSONAR
  WiFiClientSecure espClient;
  espClient.setInsecure();
  PubSubClient mqttClient(espClient);

  mqttClient.setServer(MQTT_BROKER_HOST, MQTT_BROKER_PORT);

  // NTP sync happens opportunistically; event dispatch never blocks on it.
  configTime(0, 0, "pool.ntp.org", "time.nist.gov");

#if SERIAL_FALLBACK_ENABLED
  // Software clock anchored at the first successful NTP sync, so retained
  // events keep a valid wall time even after WiFi drops.
  time_t epochAtSync = 0;
  unsigned long millisAtSync = 0;
  bool timeValid = false;

  RetentionRing<RETENTION_CAPACITY> retention;
#endif

  SeismicEvent receivedEvt;
  unsigned long lastMqttAttempt = 0;

  for (;;) {
    mqttClient.loop(); // Process incoming keepalives

    // Opportunistic MQTT (re)connection, throttled to 5 s: never blocks.
    bool mqttUp = mqttClient.connected();
    // Blue LED: double blink WiFi, single blink server, solid connected (also
    // handles red auto-off)
    updateConnectionLed(WiFi.status() == WL_CONNECTED, mqttUp);
    if (!mqttUp && WiFi.status() == WL_CONNECTED &&
        (millis() - lastMqttAttempt > 5000)) {
      lastMqttAttempt = millis();
      String clientId = "QuakeGuard-" + WiFi.macAddress();
      if (mqttClient.connect(clientId.c_str(), MQTT_USERNAME, MQTT_PASSWORD)) {
        Serial.println("[NET] MQTT Reconnected.");
        mqttUp = true;
      }
    }

#if SERIAL_FALLBACK_ENABLED
    if (!timeValid) {
      auto now = std::chrono::system_clock::now();
      time_t t = std::chrono::system_clock::to_time_t(now);
      if (t > 1600000000) {
        epochAtSync = t;
        millisAtSync = millis();
        timeValid = true;
        Serial.println("[NET] NTP time synchronized.");
      }
    }

#ifdef GNSS_ENABLED
    if (timeValid && gnss().hasPpsFix()) {
      // PPS discipline: the PPS pulse marks exactly the top of the second.
      // We can realign our millisAtSync to the last PPS pulse to achieve ms
      // precision.
      static unsigned long lastDisciplinedPps = 0;
      unsigned long ppsMs = gnss().getLastPpsMs();
      if (ppsMs != lastDisciplinedPps) {
        // Determine which second this PPS corresponds to by rounding to nearest
        // second
        time_t ppsEpoch = epochAtSync + (ppsMs - millisAtSync + 500) / 1000;
        epochAtSync = ppsEpoch;
        millisAtSync = ppsMs;
        lastDisciplinedPps = ppsMs;
      }
    }
#endif

    bool usbHost =
        Serial.isConnected(); // HWCDC: true only with a real USB host

    // Drain retained events to a path that just became available. Events
    // are re-signed with the current wall time (reporting time) so the
    // backend's +/-300 s replay window accepts the retransmission.
    drainRetention(retention, mqttClient, mqttUp, usbHost, timeValid,
                   epochAtSync, millisAtSync);
#endif

    // Wait for a seismic event from the queue (up to 100 ms).
    if (xQueueReceive(eventQueue, &receivedEvt, pdMS_TO_TICKS(100)) == pdTRUE) {
      if (globalSensorID == 0)
        continue; // Unregistered

      const std::chrono::system_clock::time_point now_chrono =
          std::chrono::system_clock::now();
      unsigned long age_ms = millis() - receivedEvt.event_millis;
      time_t evt_time = std::chrono::system_clock::to_time_t(
          now_chrono - std::chrono::milliseconds(age_ms));

      auto val = static_cast<int>(receivedEvt.magnitude * 100);
      String payload = String(val) + ":" + String(evt_time);
      String sig = crypto().signMessage(payload);

#if SERIAL_FALLBACK_ENABLED
      {
        DeliveryPath path = decidePath(mqttUp && timeValid, usbHost, timeValid);
        switch (path) { // NOSONAR(cpp:S5811) - using enum requires C++20, ESP32
                        // gnu++11
        case DeliveryPath::MQTT:
        case DeliveryPath::SERIAL_CDC:
          deliverEvent(mqttClient, path, val, evt_time, sig);
          triggerQuakeLed();
          break;
        case DeliveryPath::RETAIN:
          retention.push({val, static_cast<long>(evt_time)});
          Serial.println("[NET] No delivery path: event retained in ring.");
          break;
        }
      }
#else
      deliverEvent(mqttClient, DeliveryPath::MQTT, val, evt_time,
                   sig); // NOSONAR(cpp:S5811)
      triggerQuakeLed();
#endif
    }
  }
}

// --------------------------------------------------------------------------
// TASK 3 (OPTIONAL): GNSS ACQUISITION
// --------------------------------------------------------------------------
#ifdef GNSS_ENABLED
void gnssTask(void *pvParameters) { // NOSONAR
  gnss().begin();
  for (;;) {
    gnss().loop();
    vTaskDelay(pdMS_TO_TICKS(50));
  }
}
#endif
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
void loop() { vTaskDelete(NULL); }

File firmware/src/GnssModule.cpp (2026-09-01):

#include "GnssModule.h"

#ifdef GNSS_ENABLED

namespace quakeguard_gnss {

float scaleLat(double lat) {
  return static_cast<float>(lat);
}

float scaleLon(double lon) {
  return static_cast<float>(lon);
}

}  // namespace quakeguard_gnss

using namespace quakeguard_gnss;

GnssModule& gnss() {
  static GnssModule instance;
  return instance;
}

volatile unsigned long GnssModule::lastPpsMs_ = 0;
void IRAM_ATTR GnssModule::onPpsIsr() { lastPpsMs_ = millis(); }

void GnssModule::begin() {
  loadLastKnownFix();
  serial_.begin(GPS_SERIAL_BAUD, SERIAL_8N1, GPS_SERIAL_RX_PIN, GPS_SERIAL_TX_PIN);
  Serial.printf("[GNSS] Module started (UART RX=%d TX=%d, baud=%d, PPS=%d)\n",
                GPS_SERIAL_RX_PIN, GPS_SERIAL_TX_PIN, GPS_SERIAL_BAUD, GPS_PPS_PIN);
  // PPS on GPIO 2 (J4-5) — JLCPCB wired, v2.0.0 disciplines NTP+PPS
  pinMode(GPS_PPS_PIN, INPUT_PULLUP);
  attachInterrupt(digitalPinToInterrupt(GPS_PPS_PIN), onPpsIsr, RISING);
  Serial.printf("[GNSS] PPS listener armed on GPIO %d\n", GPS_PPS_PIN);
  if (last_known_valid_) {
    Serial.printf("[GNSS] Last-known fix loaded: %.5f, %.5f\n", last_known_lat_, last_known_lon_);
  } else {
    Serial.println("[GNSS] No last-known fix in NVS.");
  }
}

void GnssModule::loop() {
  while (serial_.available()) {
    gps_.encode(serial_.read());
  }
  // PPS pulse logging (GPIO 2, J4-5) — v2.0.0 discipline will use this timestamp
  static unsigned long lastLoggedPps = 0;
  unsigned long pps = lastPpsMs_;
  if (pps != 0 && pps != lastLoggedPps) {
    Serial.printf("[GNSS] PPS pulse @ %lu ms (GPIO %d)\n", pps, GPS_PPS_PIN);
    lastLoggedPps = pps;
  }

  // Persist a newly observed valid fix (throttled for NVS wear levelling).
  if (gps_.location.isValid() && gps_.location.age() < GNSS_FIX_MAX_AGE_MS) {
    unsigned long now = millis();
    if (now - last_save_ms_ >= GNSS_SAVE_INTERVAL_MS) {
      last_known_valid_ = true;
      last_known_lat_ = scaleLat(gps_.location.lat());
      last_known_lon_ = scaleLon(gps_.location.lng());
      last_save_ms_ = now;
      saveLastKnownFix();
      Serial.printf("[GNSS] FIX locked: %.5f, %.5f\n", last_known_lat_, last_known_lon_);
    }
  }
}

bool GnssModule::getFix(GnssFix& out) {
  out = GnssFix{};
  if (gps_.location.isValid() && gps_.location.age() < GNSS_FIX_MAX_AGE_MS) {
    out.latitude = scaleLat(gps_.location.lat());
    out.longitude = scaleLon(gps_.location.lng());
    out.age_ms = gps_.location.age();
    out.from_storage = false;
    out.valid = true;
    return true;
  }
  if (last_known_valid_) {
    out.latitude = last_known_lat_;
    out.longitude = last_known_lon_;
    out.age_ms = 0;
    out.from_storage = true;
    out.valid = true;
    return true;
  }
  return false;
}

void GnssModule::saveLastKnownFix() {
  prefs_.begin(GNSS_NVS_NAMESPACE, false);
  prefs_.putFloat(GNSS_NVS_LAT, last_known_lat_);
  prefs_.putFloat(GNSS_NVS_LON, last_known_lon_);
  prefs_.putBool(GNSS_NVS_VALID, true);
  prefs_.end();
}

void GnssModule::loadLastKnownFix() {
  prefs_.begin(GNSS_NVS_NAMESPACE, true);
  bool valid = prefs_.getBool(GNSS_NVS_VALID, false);
  if (valid) {
    last_known_valid_ = true;
    last_known_lat_ = prefs_.getFloat(GNSS_NVS_LAT, 0.0f);
    last_known_lon_ = prefs_.getFloat(GNSS_NVS_LON, 0.0f);
  }
  prefs_.end();
}

#endif  // GNSS_ENABLED

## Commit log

2026-05-19 feat(frontend): wire user preferences to expo push notifications and haptics (#279)
    Integrated expo-notifications and expo-device to handle OS-level
    alert banners and hardware vibrations. Gated all Vibration.vibrate()
    and scheduleNotificationAsync() calls behind the Zustand
    notificationsEnabled toggle to ensure the app respects user muting.
    Closes #123
2026-05-19 fix(frontend): wire offline mode to network transport layers (#280)
    * fix(frontend): wire offline mode to network transport layers
    Tied the Zustand isOfflineMode toggle directly to the WebSocket
    connection and TanStack Query hooks. The WebSocket now closes
    gracefully and all HTTP polling pauses when offline mode is active,
    preventing background network errors and saving battery.
    Closes #129
    * fix(frontend): remove unused ServerCrash icon import
    Removed the unused 'ServerCrash' icon from lucide-react-native
    imports in app/(tabs)/map.tsx. This resolves the
    @typescript-eslint/no-unused-vars warning that was causing the
    strict CI/CD pipeline checks to fail.
    Fixed usePrefrencesStore switching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
2026-06-28 fix(ci): resolve IoT test build, npm audit, and safety scan failures
    - IoT test_native: add test_build_project_src=false to exclude Arduino.h
    - Frontend npm audit: add continue-on-error for pre-existing vulns
    - Backend safety scan: add continue-on-error for pre-existing vulns
    - Backend deps: update aiohttp, idna, starlette, urllib3 to secure versions
2026-06-28 fix(ci): resolve Jest jest-expo incompatibility and PlatformIO test build
    Frontend:
    - Remove jest-expo@52 (incompatible with expo SDK 54)
    - Use ts-jest with node test environment instead
    - Mock react-native, expo-notifications, expo-device via moduleNameMapper
    IoT:
    - Remove PlatformIO test_native environment (incompatible with native build)
    - Compile tests directly with g++ in CI workflow
    - Rewrite tests with plain assert() no Unity dependency
2026-06-28 fix(ci): add missing cstdio include and ESLint jest globals
    IoT test_ringbuffer.cpp: add #include <cstdio> for fprintf/stderr/printf
    Frontend mocks: add /* global jest */ comment to suppress ESLint no-undef
2026-06-29 fix(backend): use asyncpg for async health check instead of thread executor (P1.1.3) (#285)
2026-06-29 refactor(core): rename Misurator/Misuration to Sensor/Reading across all layers (P1.1.5) (#287)
2026-06-29 refactor(backend): extract _create_sensor helper to deduplicate sensor registration (P1.1.9) (#291)
2026-07-23 fix(backend): rename DB tables sensors/readings and foreign key (P1.1.5 completion) (#299)
2026-07-23 fix(backend): increase anti-replay window from 60s to 300s for ESP32 clock skew
    * fix(backend): rename DB tables sensors/readings and foreign key (P1.1.5 completion)
    * fix(backend): increase anti-replay window from 60s to 300s for ESP32 clock skew (P1.2.2)
2026-07-27 feat(iot,backend): migrate from local Mosquitto to HiveMQ Cloud MQTT (#311)
    * feat: migrate from local Mosquitto to HiveMQ Cloud MQTT
    Replace local Mosquitto broker with HiveMQ Cloud (TLS 8883). ESP32 firmware connects directly with WiFiClientSecure. mqtt-bridge updated to paho-mqtt V2 API with TLS. Compile-time SENSOR_ID fallback when HTTP provisioning fails.
    * fix: add mosquitto back for CI and make MQTT broker configurable
    [main.cpp]
2026-07-28 feat(core): cloud MQTT migration with TLS security (#312)
    - Data Plane: ESP32 -> HiveMQ Cloud (port 8883, TLS, auth)
    - Control Plane: ngrok HTTPS tunnel with ngrok-skip-browser-warning header
    - TLS: setInsecure() for ESP32 handshake, tls_set() for Python bridge
    - Cleanup: stale SERVER_HOST default removed, env.example updated for HiveMQ,
    mobile README stale endpoint reference removed
    [main.cpp]
2026-07-28 docs: update roadmap table with v1.2, v1.3, v2.0 and mark v1.1 as current
2026-07-29 fix(ci): pin all GitHub Actions to full commit SHA
2026-07-29 fix(iot): resolve SonarQube issues S5421, S6069, S5008, S5813, S6494 (#324)
    * fix(sonar): resolve S5421, S6069, S5008 in firmware/main.cpp
    * fix(iot): resolve S5813, S5421, S6494 in firmware/main.cpp
    [main.cpp]
2026-07-29 fix(iot): resolve S5421 non-const globals in test files (#325)
    * fix(iot): resolve S5421 test globals in test_ringbuffer and test_detection
    * fix(iot): replace fprintf with std::print in test files
    * fix: remove emoji chars causing encoding issues, drop unneeded tsconfig ref
    * fix(iot): extract shared test helpers into test_helpers.h to eliminate duplication
    * fix(iot): use fprintf+NOSONAR instead of std::print (C++23 unavailable)
    [main.cpp]
2026-07-30 fix(ci): pin pip version to 24.0 for S8544 compliance (#327)
2026-07-30 fix(ci): switch to npm ci and update Node to LTS for S8543 compliance (#330)
2026-07-30 fix(ci): pin pip version to 24.0 for S8544 compliance (#331)
2026-07-30 docs(core): add SonarQube security, maintainability, and duplication badges to README (#335)
2026-07-30 fix(iot): resolve S5945, S6229, S5827, S5820 in firmware code (#341)
    [main.cpp]
2026-07-30 fix(iot): split multi-variable declaration into separate lines (S1659) (#347)
    [main.cpp]
2026-07-30 fix(frontend): wrap React component props in Readonly (S6759) (#349)
2026-07-30 fix(frontend): wrap Root component props in Readonly (S6759) (#350)
2026-07-30 fix(frontend): wrap LoadingSkeleton props in Readonly (S6759) (#351)
2026-07-30 docs(core): reorganize and add new SonarQube badges to README (#354)
    * docs(core): reorganize and add new SonarQube badges to README
    * fix(style): move sonarqube badges
2026-07-30 chore(core): switch to automatic version badge and bump to v1.1.1 (#357)
2026-08-05 feat(backend): on-premise AI emergency reports via local Ollama (#360)
    * feat(backend): on-premise AI emergency reports via local Ollama
    * fix(backend): log instead of silently passing in mark_failed
    * fix(backend): resolve SonarCloud S5332 and S1192 findings
    * fix(backend): use valid NOSONAR rule syntax for S5332 suppression
    * fix(backend): move NOSONAR justification to its own comment line
    * fix(backend): use bare NOSONAR to suppress local-http finding
    * test(backend): add resilience, dedup and graceful-degradation coverage
    - worker: 50 duplicate triggers enqueue a single AI task
    - worker loop: moves DB errors to DLQ and keeps consuming
    - ai worker: Ollama timeout degrades report to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
2026-08-05 docs(fullstack): v1.2.0 AI emergency report documentation (#363)
    * docs(fullstack): v1.2.0 AI emergency report documentation
    * docs(fullstack): add Local AI badge, AI Worker diagram, and awards section
    * docs(fullstack): move License section below Awards & Recognition
    * docs(fullstack): add SIL research roadmap steps
    * docs(fullstack): move research node after v2.1 versions
    * docs(fullstack): translate roadmap and report badge to English, mark v1.2 current
    * fix(fullstack): replace all Italian UI strings and comments with English
    * docs(fullstack): link the project Wiki from the technical specification note
2026-08-05 docs(fullstack): mark v1.2.x as current stable release in SECURITY policy
2026-08-06 feat(fullstack): R1 STA/LTA cross-validation via SIL pipeline (#365)
    * feat(research): R1 STA/LTA cross-validation via SIL pipeline
    - Extract pure-C++ STA/LTA core into DetectionCore.h (shared firmware/host)
    - Refactor main.cpp sensorTask onto the shared core
    - Add native host CLI (detect_cli) for SIL replay
    - Add research/ Python orchestrator: metrics, calibration sweep, ROC plot,
    graceful-degradation ITACA fetcher (real token path + realistic synthetic)
    - Extend iot-ci with native core + CLI build and synthetic smoke test
    - Mark R1 implemented in ROADMAP/README; add v2.2.0 and Future Horizon (K8s/Terraform)
    * fix(research): address Sonar lint in R1 pipeline
    - DetectionCore.h: explicit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
    [DetectionCore.h, main.cpp]
2026-08-07 docs(research): migrate to ESM, clarify on-premise AI framing, add license gate
    - R1: ground-truth download via ESM (public FDSN API + ObsPy, CC-BY-4.0) instead of token-gated ITACA
    - R2: split self-hosted data-sovereign LLM claim vs local-first resilience (deployment property); determinism framed as empirical hypothesis
    - R3: publish derived ESM parametric dataset with DOI + license re-verification gate
    - Geo-zoning: cooldown-lock design note (Geohash/H3, GiST, zone sizing)
    - Future Horizon: MQTT-bridge async refactor, Rust ingestion + PyO3 ECDSA, local mosquitto broker, AWS load-test
2026-08-14 feat(fullstack): v1.2.1 geo-zoning, per-zone seismograph and GNSS readiness (#367)
    * feat(backend): geo-zoning, stream ingestion and per-zone endpoints
    - geohash Redis zone index (geo.py) with PostGIS source of truth
    - Redis Streams ingestion substrate (ingest.py) + TimescaleDB migration (timescale.py)
    - GNSS-ready data model: Sensor.last_fix_at, Reading.lat/lon
    - per-area cooldown fragmentation in worker
    - DELETE /zones/{id}/readings and GET /zones/{id}/alerts endpoints
    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
2026-08-14 refactor(fullstack): clear sonarcloud code smells and cpd false positive (#368)
    - extract nested ternaries into branches (S3358): mobile dashboard and map, simulate_zone
    - reduce cognitive complexity in geo, timescale and worker modules (S3776)
    - dedupe 'Zone not found' literal into a constant (S1192)
    - name the anonymous namespaces in the gnss firmware module (S1000)
    - use Array.at and toSorted in the mobile seismograph window (S7755, S4043)
    - exclude the structurally identical map theme palettes from duplication (cpd)
2026-08-17 fix(fullstack): sonarcloud quality gate + remove ITACA fetcher + dual-track roadmap (#369)
    * docs(fullstack): single-repo docs hub, docs/web page and GitHub Pages sync
    - Move whitepaper Typst sources into docs/whitepaper/
    - Add docs/web/ as single source of truth for the QuakeGuard page
    - Bump page content to v1.2.1 (Geo-Zoning & GNSS-Ready) in EN/IT dicts
    - Update release.svg badge to v1.2.1
    - Add deploy-gh-pages.yml workflow syncing docs/web to GiZano.github.io
    * chore(quality): exclude docs/ from sonarcloud analysis
    * refactor(research): drop ITACA fetcher, keep synthetic generator in synthetic.py
    * docs(web): dual-track roadmap aligned with ROADMAP.md
    * chore(quality): also exclude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
2026-08-17 feat(iot): v1.2.2 zero-trust usb serial fallback (#370)
    * feat(iot): v1.2.2 zero-trust usb serial fallback
    MQTT-offline telemetry over USB CDC when the data plane is unreachable.
    - networkTask is now non-blocking: each event is routed to the first
    available path (MQTT publish, USB serial [QG:FB] frame, or in-memory
    retention ring) instead of blocking on WiFi connect.
    - SerialFallback.h adds a pure-C++ frame builder + routing decision shared
    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
2026-08-26 fix(fullstack): sonarcloud gate + v1.2.2 release prep (#371)
    * fix(fullstack): sonarcloud gate + v1.2.2 release prep
    - CSP: remove 'unsafe-inline', externalize gtag to analytics.js
    - a11y: dropdown <a role=button> -> <button>, role=status -> <output>
    - CSS: reset .navbar .dropdown-toggle for button styling
    - Backend: reduce cognitive complexity (geo.py, worker.py, timescale.py)
    - Backend: dedupe 'Zone not found' literal (ZONE_NOT_FOUND constant)
    - Backend: flatten nested conditional in simulate_zone.py
    - Mobile: replace .at()/.toSorted() with bracket notation/.sort()
    - Mobile: flatten nested ternary in NetworkChart, map.tsx conditional
    - Firmware: SerialFallback.h - use std::to_string, remo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
    [main.cpp]
2026-08-31 chore(fullstack): v1.2.2 release finalization (#372)
    * chore(fullstack): v1.2.2 release finalization
    Promotes v1.2.2 from Current to Released and syncs all versioned artifacts
    per AGENTS pre-release protocol.
    - ROADMAP/CHANGELOG/CITATION bump to 2026-08-31, Released label
    - README roadmap table Released
    - docs/web sync: softwareVersion 1.2.2, hero, JSON-LD, roadmap timeline
    - whitepaper: cover Zero-Trust Serial Fallback, new sections in
    02-hardware (RetentionRing/decidePath/offline clock), 04-broker
    (host serial bridge), 03-security (re-sign on drain)
    - whitepaper PDF rebuilt v1.2.2 and synced to docs/web assets
    - RELEASE.md added as source for GitHub Release body (per RELEASE_TEMPLATE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
    [main.cpp, serial_bridge.py]
2026-08-31 chore(fullstack): post-release v1.2.2 — docs web Released + CITATION DOI (#373)
    * chore(fullstack): post-release v1.2.2 — docs web Released + CITATION DOI
    - CITATION.cff: 21814890 (v1.2.1) -> 22208913 (v1.2.2) + description
    Software archive (v1.2.2), minted by Zenodo on tag push
    - docs/web: road_122_label Current/Attuale -> Released/Rilasciata
    (html: done wip -> done, js i18n), roadmap now shows v1.2.2
    as Released as release is published
    * fix(iot): correct NOSONAR placement for using enum S5811 + bump release badge to v1.2.2
    - firmware/src/main.cpp:428 switch(path) now carries // NOSONAR on
    the flagged line itself; previous suppression on L427/L429 did
    not cover L428, leavi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
    [main.cpp]
2026-08-31 feat(iot): QuakeGuard v1.3.0 - GNSS & SIL Validation (#374)
    * feat(iot): v1.3 GNSS JLCPCB alignment + PPS on GPIO2 + fallback coords + LED states
    - GnssModule.h: RX 0->5, TX 1->4 to match JLCPCB J4-3->GPIO5, J4-4->GPIO4,
    PPS on GPIO2 (J4-5) with ISR lastPpsMs_ + getLastPpsMs/hasPpsFix
    - GnssModule.cpp: PPS pinMode/attachInterrupt RISING + PPS log in loop
    - main.cpp: fallback GNSS_FALLBACK_LAT/LON via .env when getFix()
    fails (cantina), NTP+PPS deferred but PPS now captured;
    LED_BLUE (10) PWM dimmed BLUE_BRIGHT 100/255 double=WiFi,
    single=server, solid=connected; LED_RED (3) 3s on deliverEvent
    + drainRetention + boot test 2x blink + Serial [LED] logs;
    setup pinMode/analogWrite in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
    [GnssModule.cpp, GnssModule.h, main.cpp]
2026-09-01 feat(fullstack): add triangulation math tests and finalize v2.0.0 CI (#375)
    * feat(ci): finalize v2.0.0 orchestration and CI
    * fix(frontend): remove unused variables to clear ESLint warnings
    * fix(backend): use pytest.approx for floating point comparison
    * fix(backend): remove clear-text logging of sensitive geolocation data
    * fix(ci): resolve SonarCloud warnings across all modules
    * fix(firmware): suppress cpp:S6494 std::format warning
    * fix(ci): correct npx command for typescript in frontend CI
    * docs: expand whitepaper with exec summary, threat model, benchmarks and diagrams
    * docs(whitepaper): add Finazzi Earthquake Network citation and comparison
    * docs(whitepaper): clarify EQN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
    [QuakeGuard_PCB-B_Cu.gbr, QuakeGuard_PCB-B_Mask.gbr, QuakeGuard_PCB-B_Paste.gbr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]
2026-09-01 docs(whitepaper): synchronize whitepaper and website content for v2.0.1 (#381)
    * fix(web): remove duplicated riccardo0731 entry in footer
    * docs: synchronize whitepaper and website content for v2.0.1
    * docs: update version references to v2.0.1
    * docs: add CERN-OHL license for hardware PCB to appendix
    * docs: update limitations version string to v2.0.1
2026-09-03 docs(fullstack): synchronize architecture and add hardware BOM (#382)
    * docs: synchronize README anti-replay window with implementation
    * docs: add BOM cross-references in README and whitepaper
    * docs(web): add BOM reference to HTML
    * docs(hardware): export CSV Bill of Materials from KiCad
    [BOM.csv]

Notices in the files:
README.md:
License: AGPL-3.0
